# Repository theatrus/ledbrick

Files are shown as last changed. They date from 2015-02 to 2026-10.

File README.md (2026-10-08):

# LEDBrick Project





Open Hardware design for professional aquarium LED lighting systems.

## LEDBrick Plus - Modern ESP32-S3 Based Controller

The **LEDBrick Plus** is a modern, high-performance 8-channel LED driver designed for aquarium lighting applications. Built around the ESP32-S3 microcontroller and ESPHome firmware, it offers professional-grade control with smart home integration.

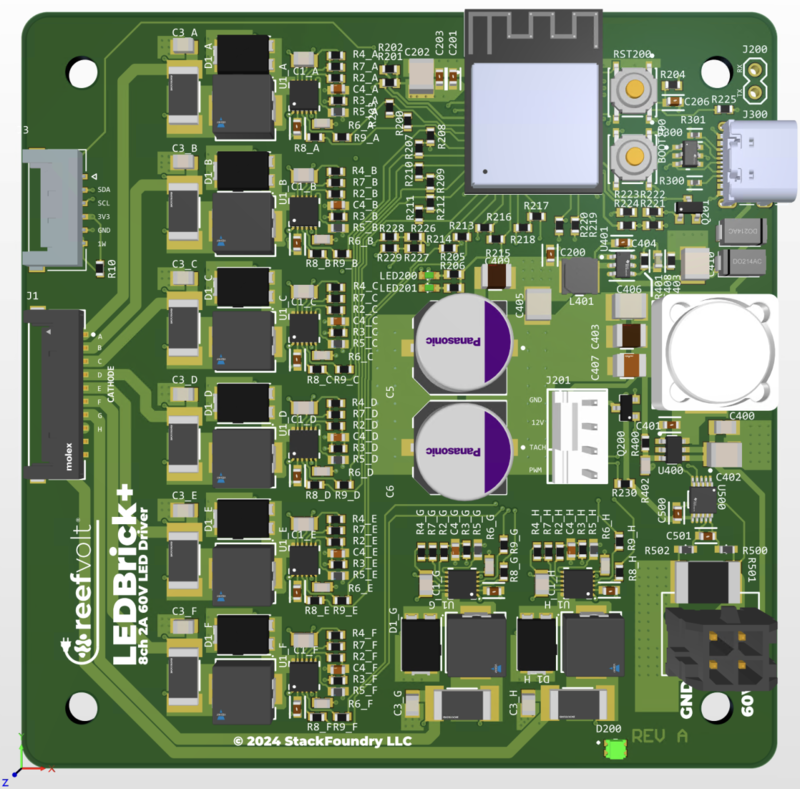
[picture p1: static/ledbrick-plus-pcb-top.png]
LEDBrick Plus PCB - Top View


*Professional 85×85mm PCB with ESP32-S3 microcontroller and 8-channel TPS922053 LED drivers*

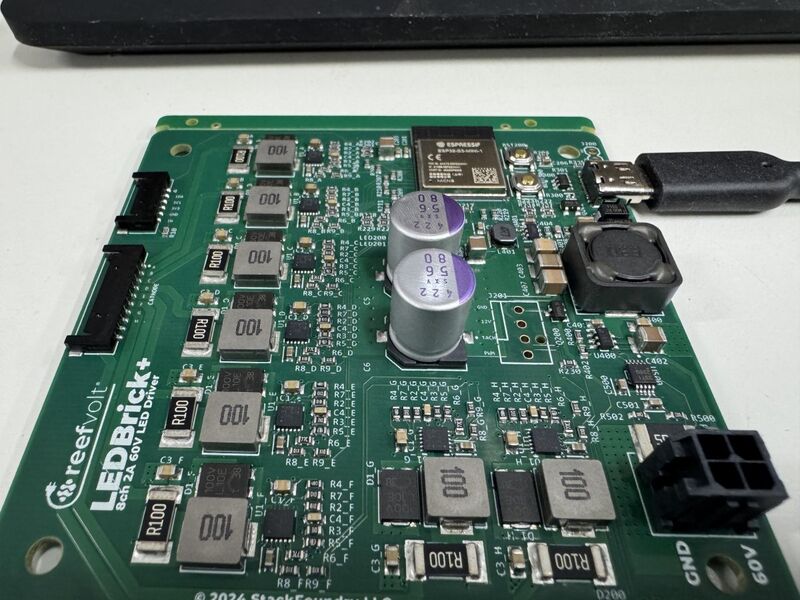
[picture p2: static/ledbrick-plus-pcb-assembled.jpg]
LEDBrick Plus PCB - Assembled


*LEDBrick Plus assembled board showing component placement and professional finish*

### 🚀 Quick Start

**Install firmware directly in your browser:**
👉 **[LEDBrick Plus Web Installer](https://theatrus.github.io/ledbrick/)**

*No downloads or software required - uses WebSerial to flash firmware directly via USB.*

### ⚡ Key Specifications

- **8 Independent LED Channels** with individual PWM and current control
- **High Current Capability**: Up to 2A per channel (scalable design)
- **Wide Voltage Range**: Supports up to 60V input
- **ESP32-S3 Microcontroller**: Dual-core with Wi-Fi connectivity
- **Two dimming controls per channel**: 1 kHz PWM dimming plus a 10 kHz current setpoint (17 PWM outputs including the fan)
- **Precision Current Control**: TPS922053 LED driver chips with 0-2A regulation
- **Environmental Monitoring**: INA228 power monitoring, I2C temperature sensors
- **Fan Control**: 4-wire fan control with RPM monitoring
- **Status Indication**: WS2812 RGB LED with customizable effects
- **Temperature Expansion**: 1-Wire bus for DS18B20 temperature sensors
- **Home Assistant Integration**: Native API with automatic discovery
- **Professional Form Factor**: 85×85mm board designed for marine environments

### 🏠 Smart Home Integration

- **ESPHome Native**: Full Home Assistant integration out of the box
- **Web Interface**: Built-in configuration and monitoring
- **OTA Updates**: Wireless firmware updates
- **MQTT Compatible**: Optional MQTT broker support
- **RESTful API**: HTTP API for custom integrations

### 🌐 Web UI Features

The LEDBrick Plus includes a professional web interface for complete control and monitoring:

#### Schedule Visualization & Control
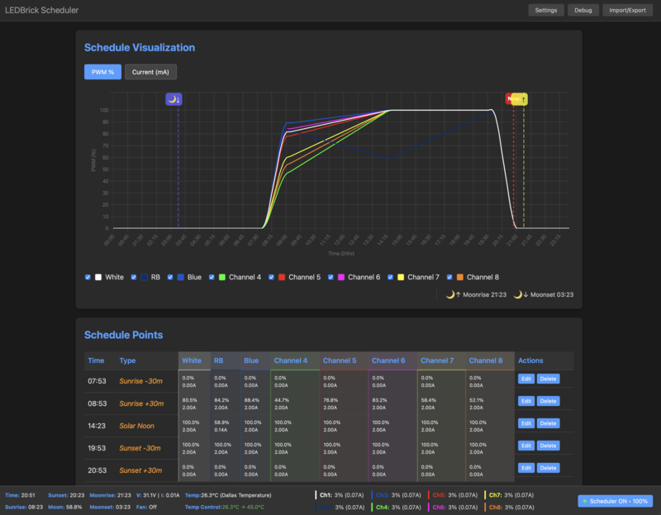
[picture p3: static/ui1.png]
LEDBrick Schedule Visualization


- **Interactive Schedule Graph**: Visual representation of all 8 channels with real-time updates
- **PWM % and Current (mA) Views**: Toggle between percentage and milliamp display modes
- **Moonrise/Moonset Indicators**: Astronomical event markers on the timeline
- **Schedule Point Editor**: Add, edit, and delete schedule points with precise timing
- **Channel Legend**: Color-coded channel identification with individual enable/disable

#### Moon Phase Simulation
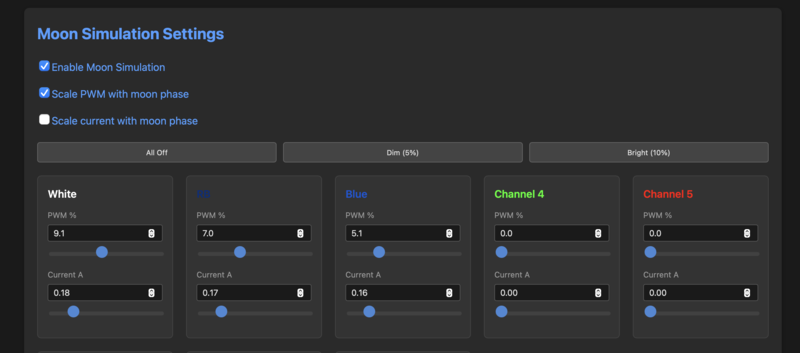
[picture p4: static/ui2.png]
Moon Phase Simulation Settings


- **Moon Phase Integration**: Automatic moon phase calculation based on location
- **PWM & Current Scaling**: Scale channel output based on current moon phase
- **Individual Channel Control**: Manual override sliders for each channel
- **Real-time Current Display**: Live monitoring of actual current draw per channel
- **Quick Presets**: All Off, Dim (5%), and Bright (10%) quick access buttons

#### Schedule Import/Export
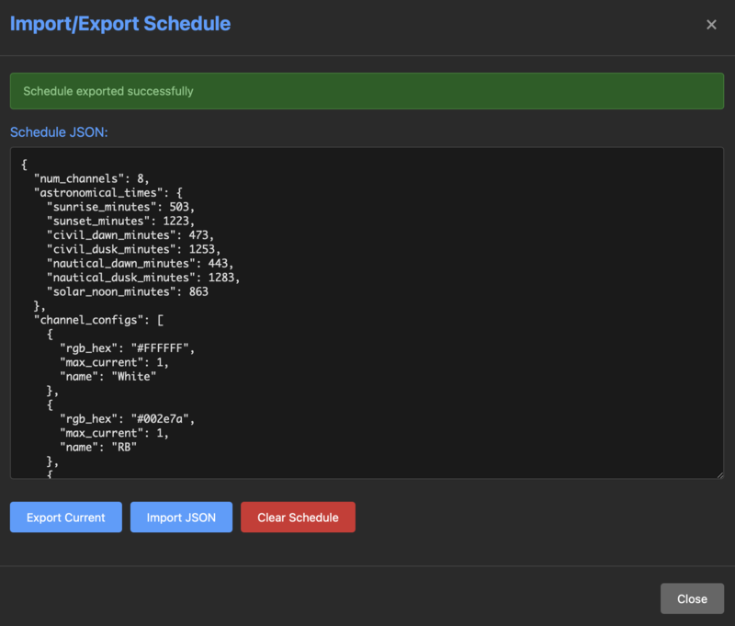
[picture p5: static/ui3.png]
Schedule Import/Export


- **JSON Format**: Human-readable schedule configuration format
- **Backup & Restore**: Export current schedule and import saved configurations
- **Clear Schedule**: Quick reset option for starting fresh
- **Astronomical Timing**: Includes sunrise/sunset offsets and timing parameters

#### Temperature Control System
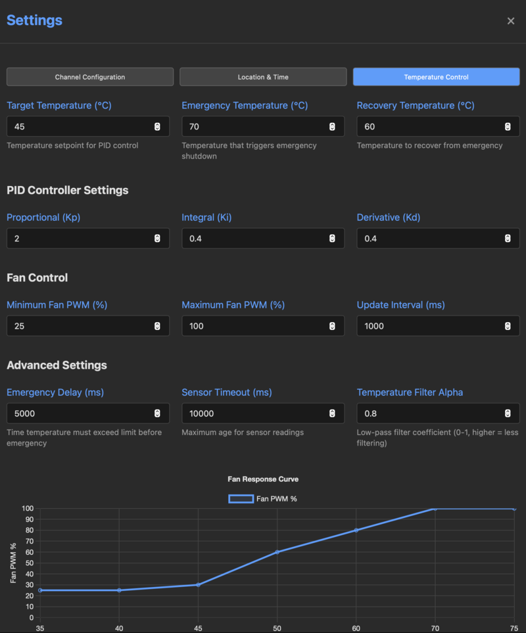
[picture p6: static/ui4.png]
Temperature Control Settings


- **PID Controller Configuration**: Adjustable Kp, Ki, Kd parameters
- **Temperature Thresholds**: Configurable target, emergency, and recovery temperatures
- **Fan Control Settings**: Min/max PWM limits and update intervals
- **Advanced Options**: Emergency delay, sensor timeout, and filter parameters
- **Fan Response Curve**: Visual representation of temperature-to-PWM mapping

#### Channel Configuration
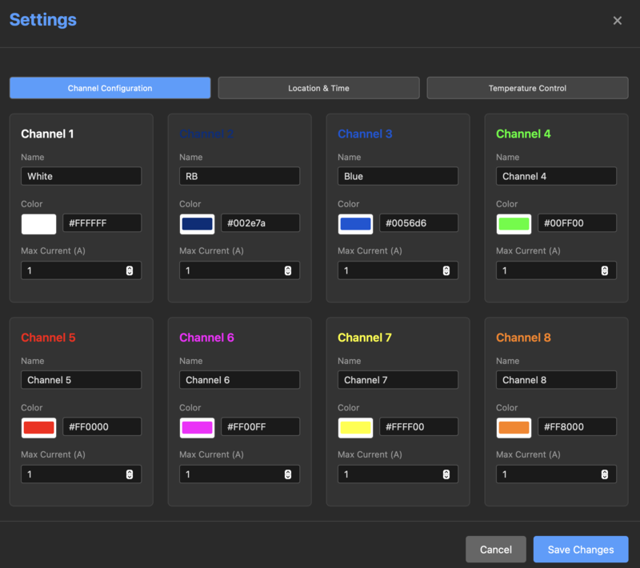
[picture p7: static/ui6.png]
Channel Configuration


- **8 Configurable Channels**: Name, color, and maximum current per channel
- **Visual Color Selection**: Color picker with hex code support
- **Current Limiting**: Hardware-enforced maximum current settings (0-2A)
- **Save/Cancel Options**: Apply changes or revert to previous settings

#### Location & Time Settings
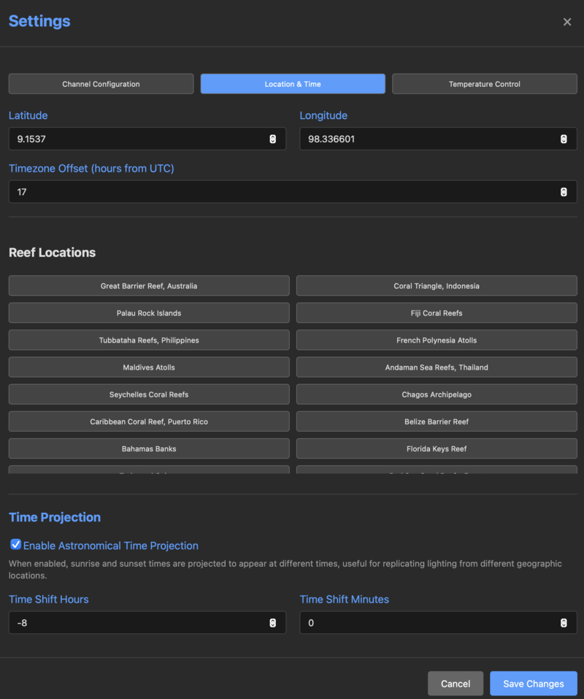
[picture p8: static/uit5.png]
Location and Time Settings


- **Geographic Configuration**: Latitude, longitude, and timezone settings
- **Reef Location Presets**: Quick selection of popular reef locations worldwide
- **Astronomical Time Projection**: Simulate lighting from remote reef locations
- **Time Shift Options**: Hour and minute offsets for schedule adjustment

### 🎛️ Advanced Control Features

- **Individual Channel Control**: Independent PWM brightness and current limiting
- **Smart Current Limiting**: Configurable per-channel maximum current with real-time enforcement
- **Programmable Schedules**: Sunrise/sunset simulation and custom lighting programs
- **Temperature Monitoring**: I2C sensor integration for thermal management
- **Power Monitoring**: Real-time current and voltage monitoring via INA228

### 🔧 Technical Details

**Microcontroller**: ESP32-S3 (Dual-core, 240MHz, Wi-Fi)
**LED Drivers**: 8× TPS922053 constant current drivers
**PWM Frequency**: 1 kHz LED dimming (LEDC), 10 kHz current setpoint (MCPWM), 16 kHz fan (MCPWM)
**Current Range**: 0-2A per channel (1A default limit)
**Input Voltage**: 12-60V DC
**Communication**: Wi-Fi, USB-C, I2C expansion
**Dimensions**: 85×85mm

For detailed forum discussion and community support, see: [Reef2Reef LEDBrick Thread](https://www.reef2reef.com/threads/ledbrick-diy-led-pendant-with-pucks.243746/)

### 📐 Hardware Design Files

Altium Designer sources, release gerbers, pick-and-place, BOM, and DRC reports live under [`hardware/`](hardware/). Two boards make up the LEDBrick Plus system:

- **[`rv_ledbrick_8ch`](hardware/rv_ledbrick_8ch.PrjPcb)** — the **controller / driver board** pictured above. Four-layer FR4 design (top, GND, PWR, bottom — see `G1`/`G2` inner plane gerbers) driven by a hierarchical schematic (`rv_ledbrick_top`, `rv_ledbrick_logic`, `TPS922053_ch`, `usb_input`, `dcdc_60v_12v`, `vin_shunt`) placing 212 components:
  - **Controller**: ESP32-S3-MINI-1-N8 (8 MB flash) with BOOT + RST tactile switches and an Amphenol 10155435 USB-C receptacle for programming and native USB.
  - **Power**: wide-VIN 60V→12V buck front-end (80V 56µF conductive-polymer bulk caps, 68µH main inductor, SS14 Schottky ORing) plus an LMR51610 low-current buck for 3.3V logic.
  - **Power monitoring**: TI INA228 with a 0.005Ω 5W metal-strip shunt on VIN for current/voltage/energy telemetry over I²C.
  - **LED channels (×8)**: TPS922053DRRR 65V/2A synchronous buck LED drivers, each with a 10µH IHLP-style composite inductor, PMEG100V100 100V Schottky flywheel, 0.1Ω 3W current-sense shunt, and an AO3400A n-channel FET + RC network for the dimming/enable input.
  - Release gerbers and pick-and-place in [`Project Outputs for rv_ledbrick_8ch/`](hardware/Project%20Outputs%20for%20rv_ledbrick_8ch/).
- **[`ledbrick_plus_led`](hardware/ledbrick_plus_led.PrjPcb)** — the **LED emitter / pendant board** the controller drives. Single-layer emitter-side copper (typical for a metal-core LED puck), single-sheet schematic, 91 placed parts split across eight channels of high-power emitters:
  - **26× Lumileds LUXEON Rubix Royal Blue** (`L1RX-RYL1000000000`, 1.5A / 1635 lm / 3.16 V each) as the blue/royal backbone.
  - **52× LUXEON C** emitters across many colors: `59`, `39`, PCA, PCB, MNT, VLT (Violet), BLU, RYL, CYN, and DRD bins.
  - **2× VIOSYS Z5** (CUN8) 8-die ultraviolet emitters.
  - 3× onboard temperature sensors: one DS18B20 (1-Wire) plus two MCP9808 (I²C, DFN + MSOP variants) for per-zone thermal feedback.
  - I/O via two Molex Pico-Lock 504050-1091 10-pin connectors and one 6-pin 5040500691 (matches the controller's output headers).
  - Release gerbers in [`ledbrick_plus_led_r0/`](hardware/ledbrick_plus_led_r0/) and [`Project Outputs for ledbrick_plus_led/`](hardware/Project%20Outputs%20for%20ledbrick_plus_led/).

EDM footprint libraries (`*-EDM/`) contain the Parasolid component models referenced by each project. See [`hardware/.gitignore`](hardware/.gitignore) for the list of Altium-generated files that are intentionally excluded.

---

## LEDBrick Classic - Original Design

The original LEDBrick design consists of two main components for DIY aquarium LED lighting.

### Emitter Board

The emitter board is a custom metal-core PCBA designed to hold 8 channels of LEDs from Cree (XP footprint), Osram (SSL and Square), Luxeon (UV and Rebel footprints).

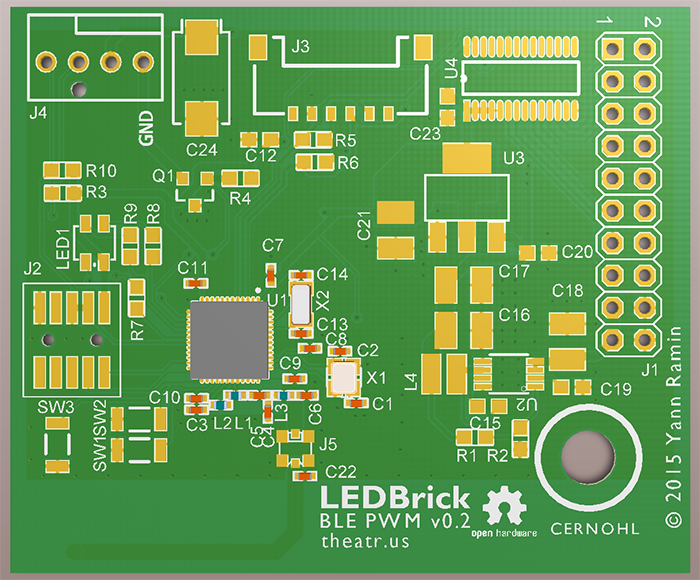
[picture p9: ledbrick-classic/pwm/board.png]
Classic PWM Board


[Design files and gerber files](ledbrick-classic/emitter-board/)

### Bluetooth Low Energy PWM Board (Legacy)

An 8 channel 24VIN + 12VOUT Fan LED dimmer board powered by a Nordic nRF51 Bluetooth Low Energy microcontroller.

[Firmware is available for both Keil and GCC compilers](ledbrick-classic/firmware/nordic_nrf51/app/ble_peripheral/ledbrick_pwm/)
[Design files and gerber files](ledbrick-classic/pwm/0.2/)

For legacy documentation and original design details, see the [ReefCentral thread](http://www.reefcentral.com/forums/showthread.php?t=2477205).

---

## Development

### Building Firmware Locally

```bash
# Install uv (Python package manager)
curl -LsSf https://astral.sh/uv/install.sh | sh

# Clone and build
git clone https://github.com/theatrus/ledbrick.git
cd ledbrick/firmware

# Quick build (runs tests, builds web UI, compiles firmware)
make esphome

# Individual components
make test           # Run all unit tests
make web            # Build React web interface
make web-debug      # Build non-minified web UI (for debugging)
make dev            # Start development server (set LEDBRICK_IP=device-ip)
make preview        # Serve minified build locally (debug minification)
make esphome-debug  # Build firmware with non-minified web UI
make clean-all      # Clean all build artifacts
make help           # Show all available targets
```

### Firmware Features

#### Advanced LED Control
- **8-Channel PWM Control**: Independent brightness and current limiting per channel
- **Smart Current Limiting**: Real-time enforcement of per-channel maximum current settings
- **Astronomical Scheduling**: Sunrise/sunset simulation with location-based timing
- **Time Projection**: Map remote reef locations to local timezone (e.g., Tahiti sunrise at 6AM Pacific)
- **Moon Phase Simulation**: Configurable moon phase effects with intensity scaling
- **Manual Override**: Direct channel control when scheduler is disabled

#### Web Interface
- **React-based UI**: Modern, responsive interface for all device settings
- **Real-time Status**: Live monitoring of channels, sensors, and system status
- **Channel Configuration**: Set names, colors, and maximum current per channel
- **Schedule Management**: Visual schedule editor with interpolation and presets
- **Location Settings**: Built-in reef location presets for accurate astronomical timing
- **Sensor Monitoring**: Display of power consumption, temperature, and fan status
- **Schedule Chart Modes**: Toggle between PWM % and Current (mA) display views
- **Debug Support**: Source maps and non-minified builds for troubleshooting

#### Sensor Integration
- **Power Monitoring**: INA228 current/voltage sensor with real-time display
- **Temperature Sensors**: DS18B20 1-wire sensors for thermal monitoring
- **Fan Control**: PWM speed control with RPM monitoring and on/off state
- **Status Bar**: Responsive layout showing all sensor data and channel status

#### Temperature Control System
- **PID Controller**: Professional-grade temperature regulation with anti-windup protection
- **Multi-Sensor Support**: Average multiple temperature sensors for accurate readings
- **Emergency Thermal Protection**: Automatic shutdown with configurable thresholds
- **Fan Curve Management**: Dynamic fan speed based on temperature with customizable curve
- **Real-time Monitoring**: Temperature status and PID performance metrics in web UI
- **Anti-Oscillation Logic**: Fan maintains minimum speed within 10°C below setpoint

#### Smart Home Integration
- **Home Assistant**: Native ESPHome integration with automatic discovery
- **RESTful API**: Complete HTTP API for schedule management and control
- **OTA Updates**: Wireless firmware updates via ESPHome
- **MQTT Support**: Optional MQTT broker integration

### Development Workflow

#### Testing and Quality Assurance
```bash
# Run unit tests for core algorithms
make test                    # All tests
make test-astro             # Astronomical calculator only
make test-scheduler         # LED scheduler only
make test-clang             # Cross-compiler validation

# Web development
LEDBRICK_IP=192.168.1.xxx make dev    # Development server with device proxy
make web                              # Production build
```

#### Architecture
- **Standalone Components**: Core algorithms (astronomical calculator, LED scheduler) are pure C++ with comprehensive unit tests
- **ESPHome Integration**: Thin wrapper components that integrate with ESPHome ecosystem
- **React Frontend**: TypeScript/React web interface with responsive design
- **Clean Separation**: Core logic can be developed and tested independently of hardware

#### Common Issues and Solutions
- **Compilation Errors**: Run `make clean-all` then `make esphome` for clean rebuild
- **Sensor Configuration**: Ensure sensor IDs match ESPHome configuration exactly
- **Web Interface Debugging**: Use `LEDBRICK_IP=device-ip make dev` for development server
- **API Testing**: Access endpoints directly at `http://device-ip/api/status` etc.

### GitHub Actions

- **Continuous Integration**: Automatic build testing on firmware changes
- **Unit Test Validation**: Standalone component testing with multiple compilers  
- **Web Publishing**: Automated deployment of web installer to GitHub Pages
- **Release Management**: Tagged releases automatically build and publish firmware

## License

Open Source Hardware - see individual component licenses for details.

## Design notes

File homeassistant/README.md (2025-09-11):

# LEDBrick Plus Home Assistant Integration

Simple, focused integration for LEDBrick Plus with Home Assistant. Supports both single unit and multi-unit tank setups.

## Features

- **Direct ESPHome Integration**: Uses native ESPHome entities and services
- **Multi-Unit Support**: Control multiple units as tank groups
- **Clean Dashboards**: Modern UI without complex automations
- **Essential Controls**: Schedule management, brightness, presets
- **Real-time Monitoring**: Power, temperature, and system status

## Quick Start

### 1. Install the Simple Package

Copy `ledbrick_simple_package.yaml` to your Home Assistant packages directory:

```bash
cp ledbrick_simple_package.yaml /config/packages/
```

Enable packages in `configuration.yaml`:
```yaml
homeassistant:
  packages: !include_dir_named packages
```

### 2. Configure Your Units

Edit the `tank_groups` helper in the package:
- **Single unit**: `{"main": ["ledbrickplus"]}`
- **Multiple units**: `{"main": ["ledbrick1", "ledbrick2"], "frag": ["ledbrick3"]}`

### 3. Add a Dashboard

Choose one of the provided dashboards:
- `ledbrick_plus_dashboard.yaml` - Single unit control
- `ledbrick_multi_unit_dashboard.yaml` - Multi-unit with tank groups

## Available Dashboards

### Single Unit Dashboard
Clean interface for controlling one LEDBrick Plus:
- Real-time channel status with colors
- System monitoring (power, temperature, fan)
- Schedule presets and controls
- Temperature control status

### Multi-Unit Dashboard  
Tank-based grouping for multiple units:
- Tank selector with unit overview
- Synchronized controls across units
- Individual unit status cards
- Group actions (brightness, scheduler, presets)

## Key Entities

Each LEDBrick Plus exposes these entities via ESPHome:

### Controls
- `switch.{device}_scheduler_enabled` - Enable/disable scheduler
- `number.{device}_pwm_scale` - Global brightness (0-100%)
- `light.{device}_ch{1-8}_pwm` - Individual channel PWM controls
- `number.{device}_ch{1-8}_current` - Channel current limits
- `number.{device}_ch{1-8}_max_current` - Maximum current settings

### Sensors
- `sensor.{device}_scheduler_pwm_channel_{1-8}` - Current PWM values
- `sensor.{device}_scheduler_current_channel_{1-8}` - Current draw
- `sensor.{device}_ina228_current` - Total current draw
- `sensor.{device}_ina228_bus_voltage` - Input voltage
- `sensor.{device}_dallas_temperature` - Heatsink temperature
- `sensor.{device}_fan_speed` - Fan RPM
- `sensor.{device}_moon_phase` - Current moon phase
- `text_sensor.{device}_ch{1-8}_color` - Channel color configuration

### Services
- `esphome.{device}_load_preset` - Load schedule preset
- `esphome.{device}_clear_schedule` - Clear all schedule points
- `esphome.{device}_set_schedule_point_8ch` - Add schedule point
- `esphome.{device}_get_schedule_json` - Export schedule
- `esphome.{device}_import_schedule_json` - Import schedule

## Simple Package Contents

The `ledbrick_simple_package.yaml` includes:

### Helpers
- `input_text.tank_groups` - JSON tank/unit mapping
- `input_select.active_tank` - Current tank selection
- `input_number.tank_brightness` - Global brightness control
- `input_boolean.sync_units` - Synchronize units toggle
- `input_boolean.feeding_mode` - Simple feeding timer

### Template Sensors
- `sensor.active_tank_units` - Unit count and list
- `sensor.tank_total_power` - Combined power usage
- `sensor.tank_average_temperature` - Average temperature
- `sensor.tank_schedule_status` - Schedule sync status

### Scripts
- `script.ledbrick_load_preset` - Load preset to all units
- `script.ledbrick_clear_schedule` - Clear schedules
- `script.ledbrick_toggle_scheduler` - Toggle schedulers
- `script.ledbrick_set_brightness` - Set brightness
- `script.ledbrick_emergency_off` - Emergency shutdown

### Automations
- Tank brightness synchronization
- Simple 10-minute feeding mode

## Installation Steps

1. **Add ESPHome Device**
   ```yaml
   esphome:
     name: ledbrickplus
     friendly_name: "LEDBrick Plus"
   ```

2. **Install Package**
   - Copy `ledbrick_simple_package.yaml` to `/config/packages/`
   - Restart Home Assistant

3. **Configure Units**
   - Go to Settings → Devices & Services → Helpers
   - Edit "Tank Group Configuration"
   - Add your unit names in JSON format

4. **Add Dashboard**
   - Go to your Lovelace dashboard
   - Add a new card
   - Paste contents from chosen dashboard YAML

## Custom Card Requirements

Install via HACS for full dashboard functionality:
- `custom:button-card` (Required for channel cards)
- `custom:auto-entities` (Required for multi-unit dashboard)
- `custom:multiple-entity-row` (Required for multi-unit dashboard)
- `card-mod` (Optional for styling)

## Tips

- Use the web UI at `http://ledbrickplus.local` for advanced configuration
- Schedule presets: `dynamic_sunrise_sunset`, `full_spectrum`, `simple`
- Moon simulation automatically follows moon phases
- Temperature control maintains safe operating temperatures
- Fan speed adjusts based on temperature

## Troubleshooting

- **Units not syncing**: Check `input_boolean.sync_units` is enabled
- **No data**: Verify ESPHome device names match configuration
- **Missing entities**: Ensure ESPHome firmware is up to date
- **Dashboard errors**: Install required custom cards via HACS

## Support

- [GitHub Issues](https://github.com/theatrus/ledbrick/issues)
- [LEDBrick Forum Thread](https://www.reef2reef.com/threads/ledbrick-diy-led-pendant-with-pucks.243746/)

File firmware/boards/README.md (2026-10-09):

# Boards

What we know about each LEDBrick board, and how to bring more boards up to date.

| Path | What it is |
| --- | --- |
| `ledbrick-plus/channels.json` | The LEDs in each channel, as built. The firmware's default channel LEDs are generated from it. |
| `ledbrick-plus/emitter_netlist.json` | The emitter and controller design files, analysed: strings, driver pins, UV LEDs, sensors, connectors. |
| `ledbrick-plus/FINDINGS.md` | Hardware findings and measurements: driver behaviour, as-built differences, flash storage, test methods. |
| `../tools/led_curves/led_models.json` | Every built-in LED model, standard LED included, with the exact values the firmware uses. Generated. |
| `../tools/led_curves/lumileds_curves.json` | The digitized Lumileds datasheet curves and the standard LED's definition. The models are built from it. |
| `../tools/board_config.py` | Back up, copy and check a board's settings over the web API. |
| `../tools/jtag/` | Read the LED driver registers over USB JTAG, to check what a board outputs. |
| `../tools/ina228_sweep.py` | Measure a channel's current steps and PWM pulse loss with the board's supply current sensor. |
| `ledbrick-plus/measurements/` | The raw data behind the findings. |

## Change the LED data

1. Edit `ledbrick-plus/channels.json` (which LEDs are in a channel) or `tools/led_curves/lumileds_curves.json` (curves).
2. From `firmware/`, run `python3 tools/led_curves/gen_led_models.py`. It rewrites `components/ledbrick_scheduler/led_models.cpp` and `tools/led_curves/led_models.json`. Commit both.
3. Run `make test-led`, then build and flash.

LEDs with no published curve go in as `standard_led`.

## Update a board

1. Back up its settings. From `firmware/`:
   ```bash
   python3 tools/board_config.py backup 192.168.1.196 backups/tank1
   ```
   This saves `schedule.json`, and `led_models.json` with any custom LED models posted to the board. `backups/` is git-ignored: backups hold the tank's schedule and location.
2. Build and flash over the network:
   ```bash
   uvx --from esphome==2026.9.1 esphome run ledbrick-plus.yaml --device 192.168.1.196
   ```
   On Windows, build from PowerShell, not Git Bash: the ESP-IDF install fails under MSYSTEM. `secrets.yaml` in git is a placeholder; use your own.
3. Wait at least a minute before any reset or power cycle. ESPHome marks a new build good after a minute of running. A reset before that rolls the board back to the previous build (boot log: "OTA rollback detected").
4. Check it:
   ```bash
   python3 tools/board_config.py check 192.168.1.196
   ```
   It lists each channel's mode and LEDs, and flags any LED model the board doesn't have.

## Copy settings to another board

```bash
python3 tools/board_config.py apply 192.168.1.197 backups/tank1
```

It posts any custom LED models first, since channels name them, then the schedule. An empty models file is skipped. The PWM scale is not copied. Edit `schedule.json` first if the boards' channels differ.

The built-in models need nothing copied: they are in the firmware. Custom models (`POST /api/led_models`) are only for a part the firmware doesn't know, and they are not normally needed.

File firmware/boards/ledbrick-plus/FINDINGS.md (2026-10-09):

# LEDBrick Plus findings

What we learned bringing up and testing a LEDBrick Plus (8-channel controller `rv_ledbrick_8ch`, emitter `ledbrick_plus_led`, ESP32-S3). Measured on one board in October 2026 unless noted.

## LED driver (TPS922053)

- **Current (ADIM/HD pin):** the driver reads the PWM duty digitally. LED current = 2 A x duty (0.1 ohm sense resistor). It resolves 8 bits up to 39 kHz and 6 bits up to 156 kHz, so one step is 7.8 mA at 8 bits. The first ADIM pulse must be at least 1 us. Minimum on-time is 100-150 ns.
- **Old firmware gave 80 mA steps.** The legacy MCPWM driver ran a 1 MHz timer at about 40 kHz: 25 counts, so only 25 current steps. INA228 supply current showed the staircase and JTAG register reads confirmed the 25-count timer.
- **Fix:** ADIM runs at 10 kHz on `mcpwm_unified`'s new driver (10 MHz timers, 1000 counts, forced levels at 0% and 100%). Pinned in `ledbrick-plus.yaml` (mcpwm_unified PRs #3 and #4, commit 2b5f4cd).
- **Hybrid dimming hazard:** if ADIM stays low while EN/PWM pulses at enable, the driver sets the current from the EN/PWM duty alone, up to 2 A. `packages/channel.yaml` holds EN/PWM off while the commanded current is below 50 mA. EN/PWM low for 57-77 ms disables the driver.
- **EN/PWM (dimming):** 1 kHz, 14-bit (LEDC).
- **The driver rounds the ADIM duty down.** The datasheet doesn't say. Stepping RBCen's command from 98 to 134 mA in 2 mA steps at 100% PWM, supply current rose once per 7.8 mA, and each edge fell where rounding down puts it (between 100 and 102 mA, 108 and 110, and so on); rounding to nearest would put each edge 4 mA lower. The curve dimmer commands mid-step, the most room either side.
- **Checked:** in curve mode at levels 37.5% and 2%, the ADIM compare and LEDC duty read over JTAG matched the dimmer run on a PC, landing on driver steps 50 and 21. LED supply off.

## PWM pulse loss

Each EN/PWM pulse gives less light than its width. Measured on RBCen (13 Rubix, about 38 V) and CW (8 LUXEON C, about 22 V) with the LED supply on, from INA228 supply current against duty at fixed current, with the other channels frozen:

- **Long pulses lose about 19 us each** (1.9% of the 1 kHz period), at 105 mA to 1.2 A on both channels. The best-conditioned fits gave 17-19.5 us; a rougher one (duties 10-60%) gave 30 us. 100% duty has no edges and loses nothing.
- **Short pulses lose less.** The loss sets in over a tail: at 1.2 A it is sharp (1% duty gives about 20% of its light, 3% about 50%); at the floor currents (about 170 mA) it is wide (3% duty gives most of its light). The firmware models light as d - 1.9% x (1 - e^(-d/tail)), with tail 1.9% at 300 mA and above and 4% at 170 mA and below.
- **The driver draws 1-4 mA more supply current** whenever its EN pin is pulsing, without light.
- **Effect on manual mode:** a manual PWM gives (duty - 1.9%) of the light at that current, so 15% PWM gives about 87% of what 15% suggests, and 5% gives about 65%.
- **The curve dimmer allows for it:** it raises each pulsed duty to give the intended light, keeps pulsed duties at or below 97.5% (shorter off-times were not measured), and converts manual settings by the light they really give. Checked on RBCen with the model: 3-25% of a step's light came out within 1% at 1.2 A and within 5% at 168 mA. Without it, 5-10% came out 20-29% dim at 168 mA.
- The INA228 cannot pin the tail below about 3% duty at low currents: the signal there is a few mA against 0.3 mA of noise. A light sensor would.
- To measure another board: `tools/ina228_sweep.py` (current staircase, or PWM sweep with a loss estimate). The data behind these numbers is in `measurements/2026-10-08/`. The sweeps use `/api/channel/control` with the scheduler off and read `/api/status` `total_current`: a new INA228 value every 5 s, averaged over about 0.5 s.

## Emitter, as built

- **WW is not as drawn.** The schematic has 4 LUXEON C 3900K, 2 Deep Red and 2 PC Amber. Built boards have PC Amber in the Deep Red places: 4 3900K and 4 PC Amber. `channels.json` has the as-built list.
- **Violet has 2 UV LEDs:** VIOSYS CUN8 (full part number not in the design files), 4th and 5th in the string. No published curve, so the firmware treats them as standard LEDs.
- **0-ohm jumpers** sit in the PCBlue (mid-string) and violet (cathode end) strings. They are not LEDs.
- **Common anode:** all 8 strings share JA1 pins 1-8; each channel's cathode comes back on JC1.
- **Temperature sensors on the emitter:** two MCP9808 (U1, U3) both at I2C address 0x18, and a DS18B20 on 1-Wire. Both MCP9808s are in the BOM and pick-and-place, so fitting both would clash on the bus. The firmware uses the DS18B20.
- **Harnesses:** the 6-pin sensor connector is mirrored between emitter and controller (pin n to pin 7-n), so that harness reverses pin order. The 10-pin LED harnesses are 1:1.
- Details, with LED designators and positions: `emitter_netlist.json`.

## LED curves

- Curves come from Lumileds DS144 (LUXEON C) and DS309 (LUXEON Rubix), digitized from the PDFs' vector paths: `tools/led_curves/lumileds_curves.json` names the figure and page for each.
- The Rubix uses DS309 2023 thermal data, which matches the emitter BOM. The 2026 revision's current curve is the same.
- Neither datasheet publishes colour or wavelength shift against current, so PWM-first dimming is the choice where colour must not move.
- **Standard LED (`standard_led`):** the point-wise median of nine LUXEON C curves (all but Deep Red), over the range they all cover. Rated 1250 mA, Rth 3.0 C/W. Five of the nine curves stop at 1050 mA; they continue along their last 100 mA to 1250 mA first. Up to 1225 mA the result lies between the real LUXEON C white and mint curves. It stands in for LEDs without a model: the UV LEDs, boards without an LED map, and models lost from flash.
- `tools/led_curves/led_models.json` has every built-in model with the exact values the firmware uses, generated alongside `led_models.cpp`.

## Fan and sensors

- Fan PWM is GPIO37 (16 kHz, inverted), enable GPIO36, tach GPIO35 with an external pull-up. A tach that reads zero while the fan spins was a connector fault, not firmware.
- The 1-Wire bus is noisy: occasional scratchpad CRC errors are normal. The firmware holds a sensor's last good value through 5 failed reads in a row.
- INA228 (I2C 0x40) measures supply voltage and current. With the LED supply on, it shows each current step.

## Settings in flash

- The NVS partition is 448 KB (`partitions.csv`). Settings use two fixed-size records: the schedule (8 KB) and custom LED models (12 KB). Any change rewrites the whole record; an unchanged record is not rewritten.
- A schedule save uses about two 4 KB pages, so each page is erased about once per 50 saves. At 100,000 erase cycles that is about 5 million saves.
- ESPHome holds preference writes for up to a minute. The firmware writes settings 250 ms after the last change, so a power cut soon after a change keeps it.

## Updating and testing

- Wait at least a minute after an OTA update before resetting. A reset before ESPHome marks the build good rolls back to the previous build.
- The USB serial log misses about 2 s after a reset, so setup messages are lost. Check boot results through the API.
- On Windows, build from PowerShell. The ESP-IDF install fails under Git Bash (MSYSTEM).
- JTAG register reads (`tools/jtag/`) show what each pin outputs, independent of the firmware's own reports. Halting the CPU stops the watchdogs, so reset afterwards.

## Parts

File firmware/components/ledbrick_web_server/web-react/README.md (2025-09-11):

# LEDBrick React Web UI

Modern React + TypeScript web interface for the LEDBrick LED controller.

## Features

- **React 18** with TypeScript for type safety
- **Vite** for fast development and optimized builds
- **Chart.js** for schedule visualization
- **Responsive design** for mobile and desktop
- **Real-time updates** via API polling
- **Compressed size**: ~47KB gzipped (includes React framework)

## Development

### Prerequisites

- Node.js 16+ and npm
- LEDBrick device on network or test server

### Quick Start

From the firmware directory:

```bash
# Start development server
make dev

# Enter your device IP when prompted
# Opens browser at http://localhost:3000
```

Or directly in this directory:

```bash
# Install dependencies
npm install

# Start dev server with device proxy
npm run dev:server

# Build production files
npm run build

# Generate C++ web content
npm run generate-cpp
```

### Available Scripts

- `npm run dev` - Start Vite dev server
- `npm run dev:server` - Start dev server with device IP prompt
- `npm run build` - Build production bundles
- `npm run build:analyze` - Build and analyze bundle size
- `npm run generate-cpp` - Generate C++ web_content.cpp
- `npm run size` - Check bundle sizes
- `npm run typecheck` - Run TypeScript type checking

## Architecture

```
web-react/
├── src/
│   ├── api/          # API client
│   ├── components/   # React components
│   ├── hooks/        # Custom React hooks
│   ├── types/        # TypeScript type definitions
│   ├── App.tsx       # Main app component
│   └── main.tsx      # Entry point
├── scripts/
│   ├── generate-web-content.js  # C++ generator
│   └── dev-server.sh           # Dev server with proxy
└── dist/             # Production build output
```

## Build Process

1. **Development**: Vite serves files with hot module replacement
2. **Production Build**: 
   - Vite bundles and minifies all code
   - Outputs: `index.html`, `app.js`, `app.css`
   - Total size: ~47KB gzipped
3. **C++ Generation**:
   - Compresses files with gzip
   - Generates `web_content.cpp` with byte arrays
   - Integrated with ESPHome build

## Size Optimization

The build is optimized for embedded use:

- **Single JS bundle** - No code splitting
- **Aggressive minification** - Terser with multiple passes
- **Gzip compression** - ~70% size reduction
- **Inline critical CSS** - Prevents flash of unstyled content
- **No source maps** - Smaller production build

## API Integration

The app communicates with the LEDBrick device via REST API:

- `/api/schedule` - Get/set schedule
- `/api/status` - Device status and current values
- `/api/presets/*` - Load built-in presets
- `/switch/*` - Control scheduler enable
- `/number/*` - Set PWM scale

## Component Structure

- **App** - Main container, state management
- **Header** - App title
- **ScheduleControls** - Enable/disable, brightness
- **ScheduleTable** - Schedule point editor
- **ScheduleChart** - Visual schedule (TODO)
- **StatusBar** - Current time, sunrise/sunset

## Future Enhancements

- [ ] Complete Chart.js integration
- [ ] Schedule point editor dialog
- [ ] Moon simulation controls
- [ ] Location/astronomical settings
- [ ] Import/export functionality
- [ ] WebSocket for real-time updates

## Troubleshooting

### Build Issues
- Run `npm run clean` to clear caches
- Check Node.js version (16+ required)
- Ensure all dependencies installed

### Dev Server Issues
- Verify device IP is correct
- Check device is on network
- Try direct API access: `http://device-ip/api/status`

### Size Concerns
- Run `npm run build:analyze` to see bundle breakdown
- Consider Preact for 3KB alternative to React
- Enable CDN loading for zero local React size

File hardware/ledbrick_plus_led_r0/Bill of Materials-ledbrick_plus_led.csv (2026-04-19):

Comment | Description | Designator | Footprint | LibRef | Quantity
CAP 0.1uF 50V X7R 0603 | Cap Ceramic 0.1uF 50V X7R 20% SMD 0603 125C Paper T/R | C1, C2, C3 | FP-CL10-IPC_B | CMP-001-00084-7 | 3
5040500691 | CONN WIRE TO BOARD RA 6POS | J1 | MOLEX_5040500691 | CMP-253-000000-2 | 1
504050-1091 | Conn Wire to Board HDR 10 POS 1.5mm Solder RA SMD Pico-Lock™ T/R | JA1, JC1 | FP-504050-1091-MFG | CMP-002-00088-1 | 2
L1RX-RYL1000000000 | LUXEON Rubix High Power LED Royal Blue Square Surface Mount 1635 lm 1.5 A 3.16 V | LED1, LED2, LED3, LED4, LED5, LED6, LED7, LED8, LED9, LED10, LED11, LED12, LED13, LED36, LED37, LED38, LED39, LED40, LED41, LED42, LED43, LED44, LED45, LED46, LED47, LED48 | L1RX-RYL1000000000-Footprint-1 | CMP-007-00052-3 | 26
L1C1-59 |  | LED14, LED15, LED16, LED21, LED22, LED23, LED57, LED58, LED59, LED60, LED61, LED62, LED63, LED64 | LUXEON_C_DATASHEET | CMP-124-0001-3 | 14
L1C1-RYL |  | LED17, LED18, LED19, LED20 | LUXEON_C_DATASHEET | CMP-124-0001-3 | 4
L1C1-PCB |  | LED24, LED25, LED26, LED27, LED30, LED31, LED32, LED33 | LUXEON_C_DATASHEET | CMP-124-0001-3 | 8
L1C1-BLU |  | LED28, LED29, LED34, LED35 | LUXEON_C_DATASHEET | CMP-124-0001-3 | 4
L1C1-VLT |  | LED49, LED50, LED51, LED54, LED55, LED56 | LUXEON_C_DATASHEET | CMP-124-0001-3 | 6
CUN8 |  | LED52, LED53 | VIOSYS_Z5 | CMP-124-0001-3 | 2
L1C1-39 |  | LED65, LED66, LED71, LED72 | LUXEON_C_DATASHEET | CMP-124-0001-3 | 4
L1C1-DRD |  | LED67, LED70 | LUXEON_C_DATASHEET | CMP-124-0001-3 | 2
L1C1-PCA |  | LED68, LED69 | LUXEON_C_DATASHEET | CMP-124-0001-3 | 2
L1C1-MNT |  | LED73, LED75, LED77, LED79 | LUXEON_C_DATASHEET | CMP-124-0001-3 | 4
L1C1-CYN |  | LED74, LED76, LED78, LED80 | LUXEON_C_DATASHEET | CMP-124-0001-3 | 4
0R 1206 | Res Jumper Thick Film 1206 0 Ohm 5% 1/4W Molded SMD Paper T/R | R1, R2 | FP-RC1206-IPC_B | CMP-009-00181-1 | 2
MCP9808T-E/MC | Temp Sensor Digital Serial (2-Wire, I2C) 8-Pin DFN EP T/R | U1 | MCHP-DFN-MC8_V | CMP-010-00024-2 | 1
DS18B20U+T&R | Temp Sensor Digital Serial (1-Wire) 8-Pin uMAX T/R | U2 | MAXM-U8+1_N | CMP-010-00025-1 | 1
MCP9808 | Temp Sensor Digital Serial (2-Wire, I2C) 8-Pin MSOP Tube | U3 | MCHP-MSOP-MS8_M | CMP-114-0012-2 | 1

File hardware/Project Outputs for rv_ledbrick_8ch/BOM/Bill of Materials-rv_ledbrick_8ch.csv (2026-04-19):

Comment | Description | Designator | Footprint | LibRef | Quantity
0R005 HOXLR2817-5W-5MR-1% | Res Metal Strip 2818 0.005 Ohm 1% 5W ±200ppm/°C Pad SMD Automotive T/R | R501 | RESC7146X09N | CMP-009-00241-2 | 1
0.1uF X7R 100V 0805 | Ceramic Capacitor, Multilayer, Ceramic, 100V, 5% +Tol, 5% -Tol, X7R, 15% TC, 0.1uF, Surface Mount, 0805 | C400 | CAPC2013X94X50ML20T25 | CMP-001-00130-1 | 1
4.7k 0603 1% | RES SMD 4.7K OHM 1% 1/10W 0603 | R10 | RESC1608-IPC-LL | CMP-009-00205-1 | 1
7.15k 0603 0.1% | Res Thin Film 0603 7.15K Ohm 0.1% 1/10W ±25ppm/°C Molded SMD SMD Punched Carrier T/R | R402 | RESC1608X55X30NL20T20 | CMP-009-00235-1 | 1
22.1k 0603 0.1% | RES SMD 22.1KOHM 0.1% 1/10W 0603 | R403 | RESC1608-IPC-LL | CMP-009-00207-3 | 1
43045-0428 | PCB Header Temperature range: max. 105 °C Housing Material: Thermoplastic Poles: 4 Rated current: 5 A | J500 | FP-43045-0428-MFG | CMP-002-00096-1 | 1
10155435-00011LF | 16 Position 5 A USB Right Angle Receptacle Connector | J300 | AMPHENOL_10155435-00011LF | CMP-243-000000-3 | 1
5040500691 | CONN WIRE TO BOARD RA 6POS | J3 | MOLEX_5040500691 | CMP-253-000000-2 | 1
C0603C560J5GACTU | Multilayer Ceramic Capacitor, 56 pF, 50 V, ± 5%, C0G (NP0), 0603 [1608 Metric] | C408 | FP-C0603C-CF-IPC_B | CMP-001-00126-1 | 1
CAP 0.47uF 1210 50V X7R | Multilayer Ceramic Capacitor, 0.47 uF, 50 V, ± 10%, X7R, 1210 [3225 Metric] | C406 | CAPC1210(3225)230_M | CMP-001-00128-1 | 1
CAP 10uF 1210 63V X7R | Multilayer Ceramic Capacitors MLCC - SMD/SMT 1210 10uF 63volts *Derate Voltage/Temp | C407 | FP-GRM32E-0_2-0_3-MFG | CMP-001-00119-1 | 1
ESP32-S3-MINI-1-N8 | Bluetooth, WiFi 802.11b/g/n, Bluetooth v5.0 Transceiver Module 2.4GHz PCB Trace Surface Mount | U200 | XCVR_ESP32-S3-MINI-1-N8 | CMP-247-000000-1 | 1
INA228AIDGST | Power Supply Support Circuit, Adjustable, 1 Channel, PDSO10 | U500 | FP-DGS0010A-IPC_C | CMP-015-00018-1 | 1
KK-254-4 | KK 254 Vertical Header, with Friction Lock, 4 Circuits, PC Tail Length: 4.00mm | J201 | KK-254-47053-3000 | CMP-133-0002-3 | 1
LMR51610XFDBVR | SIMPLE SWITCHER® power converter with 4.5V-to-65V 1A synchronous buck and 25µA quiescent current 6-SOT-23 -40 to 150 | U400 | SOT95P280X145-6N | CMP-019-00077-1 | 1
M02PTH |  | J200 | 1X02 | CMP-166-0010-1 | 1
SRN4018-4R7M | Ind Power Semi-Shielded Wirewound 4.7uH 20% 100KHz Ferrite 1.9A 1515 T/R | L401 | FP-SRN4018-MFG | CMP-006-00036-2 | 1
SRR1260-680M | Ind Power Shielded Wirewound 68uH 20% 100KHz 22Q-Factor Ferrite 2.1A T/R | L400 | SRR1260-680M-Footprint-1 | CMP-006-00034-1 | 1
TPS54202DDCR | 4.5V to 28V Input, 2A Output, EMI Friendly Synchronous Step-Down Converter 6-SOT-23-THIN -40 to 125 | U401 | FP-DDC0006A-IPC_C | CMP-019-00081-1 | 1
USBLC6-4SC6 | ESD Suppressor 15KV 6-Pin SOT-23 T/R - Product that comes on tape, but is not reeled | D300 | FP-SOT23-6L-MFG | CMP-004-00040-1 | 1
WS2812B2020 | LED; SMD; 2020; RGB; 2x2x0.84mm; 3.7Ã·5.3V; Lens: transparent; 2kHz | D200 | LED_WS2812B2020 | CMP-004-00042-1 | 1
100k 0603 1% | Res Thick Film 1.6 x 0.8 mm 100K Ohm 1% 0.1W(1/10W) 100ppm/ C Molded SMD Paper T/R | R400, R401 | RESC1608-IPC-LL | CMP-009-00203-1 | 2
100R 0603 1% | Fixed Resistor, Metal Glaze/thick Film, 0.1W, 100ohm, 75V, 1% +/-Tol, 100ppm/Cel, Surface Mount, 0603 | R500, R502 | FP-RC0603-0_55-MFG | CMP-009-00246-1 | 2
504050-1091 | Conn Wire to Board HDR 10 POS 1.5mm Solder RA SMD Pico-Lock™ T/R | J1, J4 | FP-504050-1091-MFG | CMP-002-00088-1 | 2
AC0402FR-075K1L | SMD Chip Resistor, 5.1 kOhm, ± 1%, 63 mW, 0402 [1005 Metric], Thick Film, General Purpose | R300, R301 | FP-AC0402-IPC_A | CMP-009-00234-1 | 2
AO3400A |  | Q200, Q201 | SOT23-3 | CMP-094-0000-1 | 2
CAP 22uF 25V 1210 X7R | 1210 22 uF 25 V ±20% Tolerance X7R Multilayer Ceramic Chip Capacitor | C403, C409 | FP-1210-L_3_2_0_3-W_2_5_0-MFG | CMP-001-00125-1 | 2
CAP 56uF 80V Poly | Conductive Polymer Aluminum Solid Capacitor 56uF 20% 80V Surface Mount T/R | C5, C6 | FP-OS-CON-SMT-F12-MFG | CMP-001-00120-1 | 2
LED0603 |  | LED200, LED201 | LED-0603 | CMP-130-0000-1 | 2
PTS526SK15SMTR2LFS | Switch Tactile N.O. SPST Round Button Gull Wing 0.05A 12VDC 200000Cycles 2.45N SMD T/R | BOOT200, RST200 | FP-PTS526SK15SMTR2LFS-MFG | CMP-011-00015-1 | 2
SS14 |  | D400, D401 | SMA | CMP-080-0002-2 | 2
1K 0603 1% | Res Thick Film 0603 1K Ohm 1% 1/10W ±100ppm/°C Molded SMD Punched Carrier T/R | R205, R206, R230 | RESC1608-IPC-ML | CMP-009-00193-3 | 3
CAP 4.7uF 50V X7R 1210 | CAP CER 4.7UF 50V X7R 1210 | C202, C402, C405, C410 | CAPC3225X20N | CMP-001-00083-3 | 4
CAP 0.1uF 50V X7R 0603 | Cap Ceramic 0.1uF 50V X7R 20% SMD 0603 125C Paper T/R | C200, C201, C401, C404, C500, C501 | FP-CL10-IPC_B | CMP-001-00084-7 | 6
0.001uF 50V 0603 X7R | Ceramic Capacitor, Multilayer, Ceramic, 50V, 10% +Tol, 10% -Tol, X7R, 15% TC, 0.001uF, Surface Mount, 0603 | C4_A, C4_B, C4_C, C4_D, C4_E, C4_F, C4_G, C4_H | FP-0603-L_1_6_0_15-W_0_81-IPC_B | CMP-001-00131-2 | 8
1K 0603 1% | Res Thick Film 0603 1K Ohm 1% 1/10W ±100ppm/°C Molded SMD Punched Carrier T/R | R2_A, R2_B, R2_C, R2_D, R2_E, R2_F, R2_G, R2_H | RESC1608-IPC-NL | CMP-009-00193-3 | 8
1M 0603 1% | VISHAY - CRCW06031M00FKEAHP - RES, AEC-Q200, THICK FILM, 1M, 0603 | R3_A, R3_B, R3_C, R3_D, R3_E, R3_F, R3_G, R3_H | RESC1608-IPC-NL | CMP-009-00187-4 | 8
10K 0603 1% | Res General Purpose Thick Film 0603 10K Ohm 1% 1/10W ±100ppm/°C Molded SMD Paper T/R | R201, R202, R204, R221, R222, R223, R226, R227 | RESC1608-IPC-ML | CMP-009-00191-4 | 8
18k 0603 | Fixed Resistor, Metal Glaze/thick Film, 0.1W, 18000ohm, 75V, 1% +/-Tol, 100ppm/Cel, Surface Mount, 0603 | R5_A, R5_B, R5_C, R5_D, R5_E, R5_F, R5_G, R5_H | FP-CRCW0603-e3-IPC_B | CMP-009-00244-2 | 8
100k 0603 1% | Res Thick Film 1.6 x 0.8 mm 100K Ohm 1% 0.1W(1/10W) 100ppm/ C Molded SMD Paper T/R | R7_A, R7_B, R7_C, R7_D, R7_E, R7_F, R7_G, R7_H | RESC1608-IPC-NL | CMP-009-00203-1 | 8
309k 0603 1% | Res Thick Film 0603 309K Ohm 1% 0.1W(1/10W) ±100ppm/C Molded SMD Paper T/R | R4_A, R4_B, R4_C, R4_D, R4_E, R4_F, R4_G, R4_H | RESC1608-IPC-NL | CMP-009-00208-2 | 8
ERJ-3EKF6192V | Fixed Resistor, Metal Glaze/thick Film, 0.1W, 61900ohm, 75V, 1% +/-Tol, 100ppm/Cel, Surface Mount, 0603 | R6_A, R6_B, R6_C, R6_D, R6_E, R6_F, R6_G, R6_H | RESC1608X55X30ML15T15 | CMP-009-00245-1 | 8
MFL12HR100FT | Fixed Resistor, Metal Strip, 3W, 0.1ohm, 5.48V, 1% +/-Tol, 50ppm/Cel, Surface Mount, 2513 | R1_A, R1_B, R1_C, R1_D, R1_E, R1_F, R1_G, R1_H | FP-CRA2512-MFG | CMP-009-00243-1 | 8
MWSA0603S-100MT | General Purpose Inductor, 10uH, 20%, 1 Element, Composite-Core, SMD, 2525 | L1_A, L1_B, L1_C, L1_D, L1_E, L1_F, L1_G, L1_H | FP-IHLP-2525CZ-FP_2_413x3-MFG | CMP-006-00037-1 | 8
PMEG100V100ELPDZ | Rectifier Diode, Schottky, 1 Phase, 1 Element, 100V V(RRM), Silicon | D1_A, D1_B, D1_C, D1_D, D1_E, D1_F, D1_G, D1_H | DFN355P580X82-3N | CMP-004-00041-2 | 8
TPS922053DRRR | 65-V, 2-A buck LED driver with inductive fast dimming and spread spectrum 12-WSON -40 to 125 | U1_A, U1_B, U1_C, U1_D, U1_E, U1_F, U1_G, U1_H | SON50P300X100_HS-13N | CMP-019-00085-2 | 8
CAP 1uF 10V X7R 0603 | Cap Ceramic 1uF 10V X7R 10% SMD 0603 125C Paper T/R | C2_A, C2_B, C2_C, C2_D, C2_E, C2_F, C2_G, C2_H, C203, C206 | FP-CL10-IPC_B | CMP-001-00085-7 | 10
0.1uF X7R 100V 0805 | Ceramic Capacitor, Multilayer, Ceramic, 100V, 5% +Tol, 5% -Tol, X7R, 15% TC, 0.1uF, Surface Mount, 0805 | C1_A, C1_B, C1_C, C1_D, C1_E, C1_F, C1_G, C1_H, C3_A, C3_B, C3_C, C3_D, C3_E, C3_F, C3_G, C3_H | CAPC2013X94X50NL20T25 | CMP-001-00130-1 | 16
10K 0603 1% | Res General Purpose Thick Film 0603 10K Ohm 1% 1/10W ±100ppm/°C Molded SMD Paper T/R | R200, R203, R207, R208, R209, R210, R211, R212, R213, R214, R215, R216, R217, R218, R219, R220, R225 | RESC1608-IPC-NL | CMP-009-00191-4 | 17
10R 0603 1% | YAGEO (PHYCOMP) - RC0603FR-0710RL - RES, THICK FILM, 10R, 1%, 0.1W, 0603 | R8_A, R8_B, R8_C, R8_D, R8_E, R8_F, R8_G, R8_H, R9_A, R9_B, R9_C, R9_D, R9_E, R9_F, R9_G, R9_H, R224, R228, R229 | RESC1608-IPC-NL | CMP-009-00180-2 | 19

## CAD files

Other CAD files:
hardware/ledbrick_plus_led-EDM/FP-504050-1091-MFG_CMP-002-00088-1.x_t
hardware/ledbrick_plus_led-EDM/FP-CL10-IPC_B_CMP-001-00084-7.x_t
hardware/ledbrick_plus_led-EDM/FP-RC1206-IPC_B_CMP-009-00181-1.x_t
hardware/ledbrick_plus_led-EDM/L1RX-RYL1000000000-Footprint-1_CMP-007-00052-3.x_t
hardware/ledbrick_plus_led-EDM/LUXEON_C_DATASHEET_CMP-124-0001-3.x_t
hardware/ledbrick_plus_led-EDM/LUXEON_C_WIDE_CMP-124-0001-2.x_t
hardware/ledbrick_plus_led-EDM/MAXM-U8+1_N_CMP-010-00025-1.x_t
hardware/ledbrick_plus_led-EDM/MCHP-DFN-MC8_V_CMP-010-00024-2.x_t
hardware/ledbrick_plus_led-EDM/MCHP-MSOP-MS8_M_CMP-114-0012-2.x_t
hardware/ledbrick_plus_led-EDM/MOLEX_5040500691_CMP-253-000000-2.x_t
hardware/ledbrick_plus_led-EDM/VIOSYS_Z5_CMP-124-0001-3.x_t
hardware/rv_ledbrick_8ch-EDM/AMPHENOL_10155435-00011LF_CMP-243-000000-3.x_t
hardware/rv_ledbrick_8ch-EDM/CAPC1210(3225)230_M_CMP-001-00128-1.x_t
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

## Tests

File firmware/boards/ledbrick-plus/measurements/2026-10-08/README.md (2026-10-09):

# Driver measurements, 2026-10-08

One LEDBrick Plus, LED supply on (50.9 V), other channels frozen at their schedule values. Each file lists the commands sent (`pwm` in %, `current` in A) and the INA228 supply current readings (A) after each, plus readings with the channel off (`baselines`). Channels are 1-based. Findings: `../../FINDINGS.md`.

| File | Channel | What |
| --- | --- | --- |
| `staircase_ch5.json` | 5 RBCen | 100% PWM, current 98-134 mA in 2 mA steps: driver steps and rounding |
| `pwm_sweep_ch5.json` | 5 | Duty 1-25% at 1.2 A and 164 mA |
| `pwm_sweep2_ch5.json` | 5 | Duty 2-100% at 164 and 300 mA |
| `pwm_sweep_ch2.json` | 2 CW | Duty 2-100% at 105 and 200 mA, 2-15% at 1.0 A |
| `pwm_high_ch2.json` | 2 | Duty 40-100% at 105 and 200 mA: pulse loss near full duty |
| `pwm_high_ch5.json` | 5 | Duty 40-100% at 164 mA |
| `floor_check_ch5.json` | 5 | 168 mA: shares 2-25% sent as plain duty (`old`) and with the first loss model (`new`) |
| `floor_check2_ch5.json` | 5 | 168 mA: shares 2-25% with the final loss model |
| `pwmfirst_check_ch5.json` | 5 | 1.2 A: shares 2-25% with the final loss model |
| `tool_pwm_ch5.json`, `tool_stair_ch5.json` | 5 | Trial runs of `tools/ina228_sweep.py` |

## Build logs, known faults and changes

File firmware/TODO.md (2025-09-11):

# LEDBrick Scheduler - Home Assistant Services Implementation

## Overview
The LEDBrick Scheduler C++ component includes a planned Home Assistant services architecture that was partially implemented but needs completion due to ESPHome API service registration complexity.

## Planned Services Architecture

### 1. Schedule Management Services

#### `ledbrick_scheduler.set_schedule_point`
**Purpose:** Add or update a schedule point for all channels
**Parameters:**
- `time_minutes` (int, 0-1439): Time in minutes from midnight (e.g., 480 = 8:00 AM)
- `pwm_values` (float array): PWM percentages (0-100) for each channel
- `current_values` (float array): Current values (0-2A) for each channel

**Example Usage:**
```yaml
# Home Assistant automation
service: ledbrick_scheduler.set_schedule_point
data:
  time_minutes: 480  # 8:00 AM
  pwm_values: [0, 20, 60, 80, 60, 40, 20, 0]  # 8 channels
  current_values: [0, 0.3, 1.0, 1.5, 1.0, 0.6, 0.3, 0]
```

#### `ledbrick_scheduler.remove_schedule_point`
**Purpose:** Remove a schedule point at specific time
**Parameters:**
- `time_minutes` (int): Time point to remove

#### `ledbrick_scheduler.clear_schedule`
**Purpose:** Remove all schedule points
**Parameters:** None

### 2. Preset Management Services

#### `ledbrick_scheduler.load_preset`
**Purpose:** Load a built-in or saved preset schedule
**Parameters:**
- `preset_name` (string): Name of preset to load

**Built-in Presets:**
- `sunrise_sunset`: Natural lighting cycle (4 points: dawn, noon, dusk, night)
- `full_spectrum`: High-intensity full spectrum (4 points: morning, midday, afternoon, evening)
- `simple`: Basic on/off schedule (2 points: 8AM on, 8PM off)

**Example Usage:**
```yaml
service: ledbrick_scheduler.load_preset
data:
  preset_name: "sunrise_sunset"
```

#### `ledbrick_scheduler.save_preset`
**Purpose:** Save current schedule as named preset
**Parameters:**
- `preset_name` (string): Name for the new preset

### 3. Control Services

#### `ledbrick_scheduler.set_enabled`
**Purpose:** Enable or disable the scheduler
**Parameters:**
- `enabled` (boolean): True to enable, false to disable

#### `ledbrick_scheduler.get_status`
**Purpose:** Get current scheduler status and interpolated values
**Parameters:** None
**Returns:** Fires Home Assistant event with current status

### 4. Advanced Services (Future)

#### `ledbrick_scheduler.set_interpolation_curve`
**Purpose:** Change interpolation method between schedule points
**Parameters:**
- `curve_type` (string): "linear", "smooth", "bezier"

#### `ledbrick_scheduler.sync_sunrise_sunset`
**Purpose:** Automatically sync schedule points to sunrise/sunset times
**Parameters:**
- `location` (object): Latitude/longitude for sun calculations

## Current Implementation Status

### ✅ Completed (Updated Implementation)
- **C++ Component**: Professional LEDBrickScheduler class with complete scheduling logic
- **Python Integration**: ESPHome codegen integration and automation actions
- **Template-Based Services**: Native ESPHome service system with individual channel parameters
- **Local Storage**: Binary format persistence to ESP32 flash memory (4KB storage)
- **Home Assistant Integration**: Complete UI helpers, scripts, and automations
- **Preset System**: Built-in presets (sunrise_sunset, full_spectrum, simple)
- **Linear Interpolation**: Smooth transitions between schedule points
- **Current Limiting**: Per-channel maximum current enforcement
- **Status Reporting**: Template sensors for monitoring scheduler state

### ✅ Working Services (Template-Based Approach)
- `set_schedule_point_8ch` - Set schedule point for all 8 channels
- `set_schedule_point_4ch` - Simplified 4-channel version for testing  
- `remove_schedule_point` - Remove schedule point at specific time
- `clear_schedule` - Remove all schedule points
- `load_preset` - Load built-in or saved presets
- `save_preset` - Save current schedule as named preset
- `set_scheduler_enabled` - Enable/disable scheduler
- `get_scheduler_status` - Log current status and values
- `export_schedule` - Export schedule as JSON to logs
- `save_to_flash` / `load_from_flash` - Manual flash storage operations

### ❌ Previous Approach (Documented as Not Working)
- ESPHome CustomAPIDevice service registration with `std::vector<float>` parameters
- Direct C++ service method binding (linking errors)
- Complex parameter type serialization (template specialization issues)

## Implementation Approaches

### ✅ Option 2: ESPHome Native Services (IMPLEMENTED)
**Status:** Successfully implemented and tested
**Approach:** Define services in YAML and connect to component methods via lambda functions
**Benefits:**
- No linking issues with complex parameter types
- Works with existing ESPHome infrastructure
- Full control over parameter validation and conversion
- Easy to extend and modify

**Example Implementation:**
```yaml
api:
  services:
    - service: set_schedule_point_8ch
      variables:
        time_minutes: int
        pwm_ch1: float
        pwm_ch2: float
        # ... all 8 channels for both PWM and current
      then:
        - lambda: |-
            std::vector<float> pwm_values = {pwm_ch1, pwm_ch2, pwm_ch3, pwm_ch4, pwm_ch5, pwm_ch6, pwm_ch7, pwm_ch8};
            std::vector<float> current_values = {current_ch1, current_ch2, current_ch3, current_ch4, current_ch5, current_ch6, current_ch7, current_ch8};
            id(main_scheduler).set_schedule_point(time_minutes, pwm_values, current_values);
```

### ❌ Option 1: ESPHome CustomAPIDevice Services (FAILED)
**Status:** Attempted but blocked by linking errors
**Issue:** ESPHome's CustomAPIDevice has incomplete template specializations for `std::vector<float>` parameters
**Conclusion:** Not viable with current ESPHome version

### ✅ Option 3: Home Assistant Template Integration (IMPLEMENTED)
**Status:** Complete with UI helpers, scripts, and automations
**Approach:** Home Assistant provides rich UI and logic, calls ESPHome services with individual parameters
**Benefits:**
- Rich Home Assistant dashboard integration
- Input helpers for easy configuration
- Automated scheduling via time-based automations
- Script shortcuts for common configurations

## Implementation Complete

### ✅ Ready for Use
The LEDBrick Scheduler is now fully implemented with:

1. **ESPHome Component**: Professional C++ scheduler with flash storage (`components/ledbrick_scheduler/`)
2. **Service Integration**: Template-based services for Home Assistant (`packages/scheduler_services.yaml`)  
3. **Home Assistant Helpers**: Complete UI and automation configuration (`homeassistant_integration.yaml`)
4. **Test Configuration**: Working example with all 8 channels (`test_scheduler_with_services.yaml`)

### Quick Start
1. **Enable in LEDBrick**: Uncomment scheduler package line in `ledbrick-plus.yaml:78`
2. **Add External Component**: Include scheduler component in configuration
3. **Import HA Config**: Copy `homeassistant_integration.yaml` to Home Assistant
4. **Configure Schedule**: Use Home Assistant UI or call services directly

### Usage Examples
```bash
# Load a preset via ESPHome service
service: esphome.ledbrickplus_load_preset
data:
  preset_name: "sunrise_sunset"

# Set custom schedule point  
service: esphome.ledbrickplus_set_schedule_point_8ch
data:
  time_minutes: 480  # 8:00 AM
  pwm_ch1: 0
  pwm_ch2: 20
  # ... etc for all channels
```

## Service Interface Design Goals

- **Simple:** Easy to call from Home Assistant automations
- **Flexible:** Support both individual channel control and preset loading  
- **Efficient:** Minimal Home Assistant entity overhead
- **Extensible:** Easy to add advanced features like curve interpolation
- **Robust:** Proper error handling and validation

## Example Home Assistant Integration

```yaml
# automation.yaml
automation:
  - alias: "Morning Lighting Schedule"
    trigger:
      - platform: time
        at: "06:00:00"
    action:
      - service: ledbrick_scheduler.load_preset
        data:
          preset_name: "sunrise_sunset"
      - service: ledbrick_scheduler.set_enabled
        data:
          enabled: true

  - alias: "Custom Evening Lighting"  
    trigger:
      - platform: time
        at: "20:00:00"
    action:
      - service: ledbrick_scheduler.set_schedule_point
        data:
          time_minutes: 1200  # 8 PM
          pwm_values: [10, 20, 30, 40, 30, 20, 10, 5]
          current_values: [0.2, 0.4, 0.6, 0.8, 0.6, 0.4, 0.2, 0.1]
```

This architecture provides a clean, professional interface for managing complex lighting schedules while maintaining the performance benefits of the C++ implementation.

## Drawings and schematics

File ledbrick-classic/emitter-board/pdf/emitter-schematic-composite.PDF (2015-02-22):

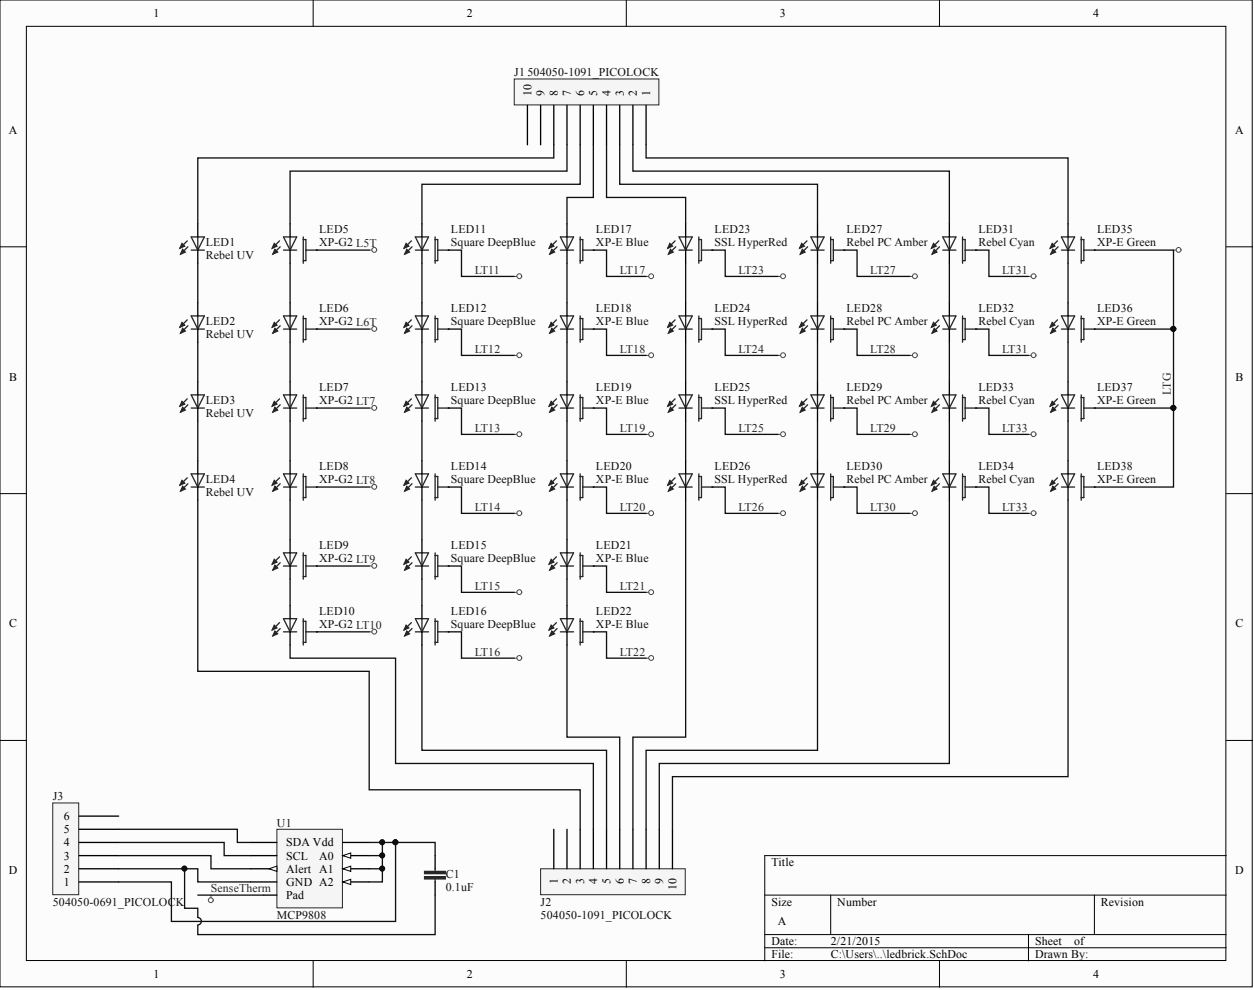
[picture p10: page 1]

SCL A0 Alert A1 GND A2 Pad

SenseTherm

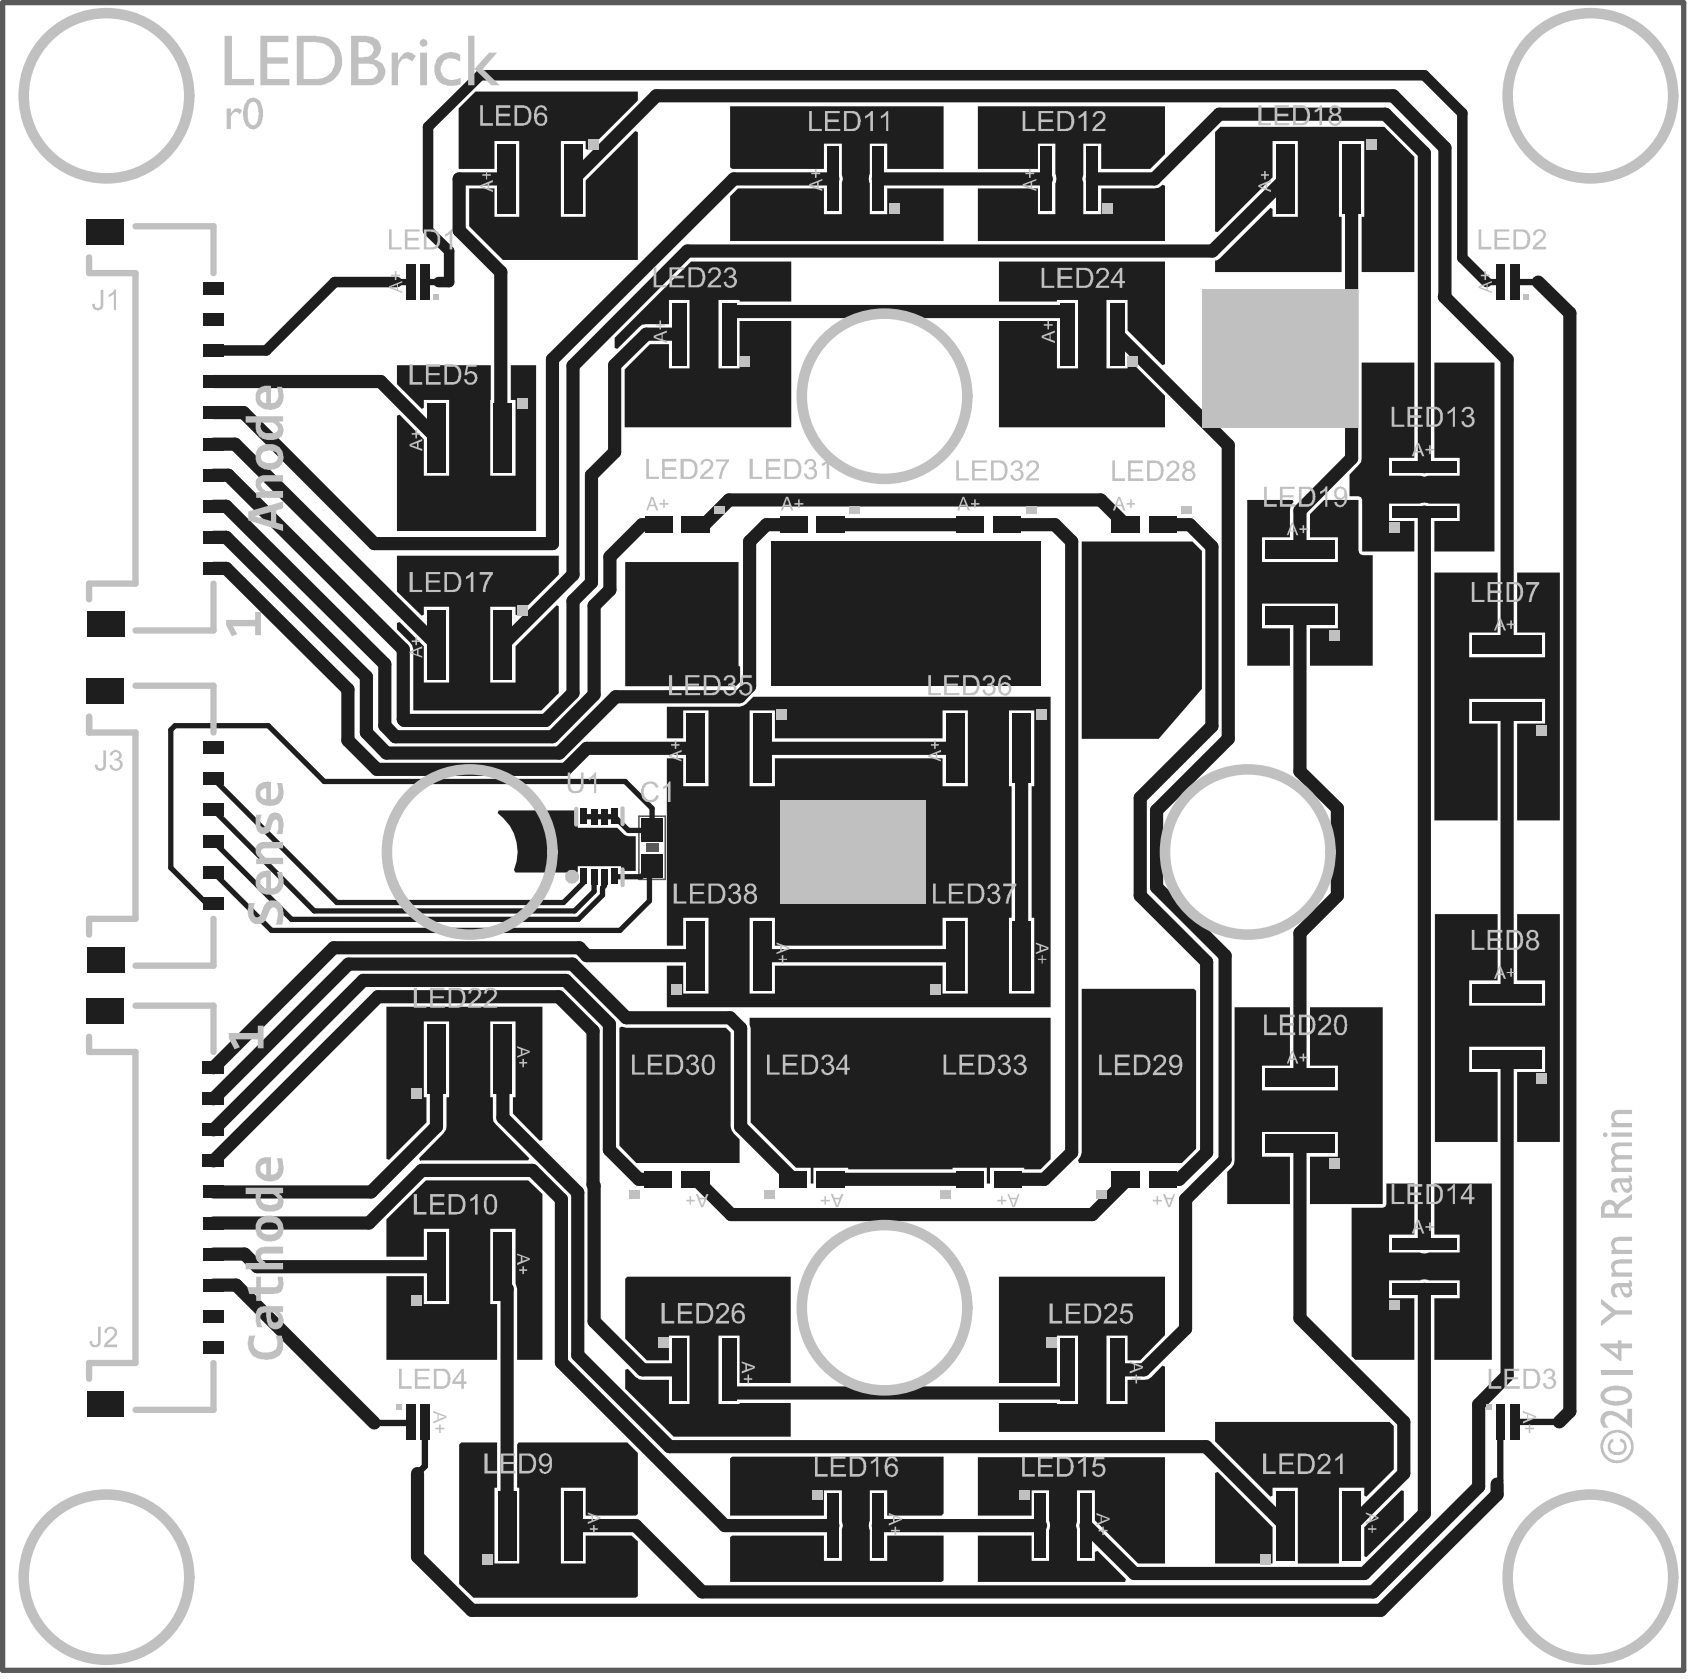
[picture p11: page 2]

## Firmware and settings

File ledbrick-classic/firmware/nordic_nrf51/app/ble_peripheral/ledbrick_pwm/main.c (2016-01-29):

/* Copyright (c) 2014 Nordic Semiconductor. All Rights Reserved.
 *
 * The information contained herein is property of Nordic Semiconductor ASA.
 * Terms and conditions of usage are described in detail in NORDIC
 * SEMICONDUCTOR STANDARD SOFTWARE LICENSE AGREEMENT.
 *
 * Licensees are granted free, non-transferable use of the information. NO
 * WARRANTY of ANY KIND is provided. This heading must NOT be removed from
 * the file.
 *
 */

/** @file
 *
 * @defgroup ble_sdk_app_template_main main.c
 * @{
 * @ingroup ble_sdk_app_template
 * @brief Template project main file.
 *
 * This file contains a template for creating a new application. It has the code necessary to wakeup
 * from button, advertise, get a connection restart advertising on disconnect and if no new
 * connection created go back to system-off mode.
 * It can easily be used as a starting point for creating a new application, the comments identified
 * with 'YOUR_JOB' indicates where and how you can customize.
 */

#include <stdint.h>
#include <string.h>
#include <inttypes.h>
#include "nordic_common.h"
#include "nrf.h"
#include "app_error.h"
#include "nrf51_bitfields.h"
#include "ble.h"
#include "ble_hci.h"
#include "ble_srv_common.h"
#include "ble_advdata.h"
#include "ble_advertising.h"
#include "ble_conn_params.h"
#include "boards.h"
#include "softdevice_handler.h"
#include "app_timer.h"
#include "device_manager.h"
#include "pstorage.h"
#include "app_trace.h"
#include "bsp.h"
#include "bsp_btn_ble.h"
#include "ble_lbs.h"
#include "twi_master.h"
#include "pca9685.h"
#include "mcp9808.h"
#include "fan_monitor.h"
#include "error_handlers.h"

#define IS_SRVC_CHANGED_CHARACT_PRESENT  1                                          /**< Include or not the service_changed characteristic. if not enabled, the server's database cannot be changed for the lifetime of the device*/

#define DEVICE_NAME                      "LEDBrick-PWM"                               /**< Name of device. Will be included in the advertising data. */
#define MANUFACTURER_NAME                "theatr.us"                      /**< Manufacturer. Will be passed to Device Information Service. */
#define APP_ADV_INTERVAL                 300                                        /**< The advertising interval (in units of 0.625 ms. This value corresponds to 25 ms). */
#define APP_ADV_TIMEOUT_IN_SECONDS       86400                                        /**< The advertising timeout in units of seconds. */

#define APP_TIMER_PRESCALER              0                                          /**< Value of the RTC1 PRESCALER register. */
#define APP_TIMER_MAX_TIMERS             (7+BSP_APP_TIMERS_NUMBER)                  /**< Maximum number of simultaneously created timers. */
#define APP_TIMER_OP_QUEUE_SIZE          8                                          /**< Size of timer operation queues. */

#define MIN_CONN_INTERVAL                MSEC_TO_UNITS(50, UNIT_1_25_MS)           /**< Minimum acceptable connection interval (0.05 seconds). */
#define MAX_CONN_INTERVAL                MSEC_TO_UNITS(200, UNIT_1_25_MS)           /**< Maximum acceptable connection interval (.2 second). */
#define SLAVE_LATENCY                    0                                          /**< Slave latency. */
#define CONN_SUP_TIMEOUT                 MSEC_TO_UNITS(4000, UNIT_10_MS)            /**< Connection supervisory timeout (4 seconds). */

#define FIRST_CONN_PARAMS_UPDATE_DELAY   APP_TIMER_TICKS(5000, APP_TIMER_PRESCALER) /**< Time from initiating event (connect or start of notification) to first time sd_ble_gap_conn_param_update is called (5 seconds). */
#define NEXT_CONN_PARAMS_UPDATE_DELAY    APP_TIMER_TICKS(30000, APP_TIMER_PRESCALER)/**< Time between each call to sd_ble_gap_conn_param_update after the first call (30 seconds). */
#define MAX_CONN_PARAMS_UPDATE_COUNT     3                                          /**< Number of attempts before giving up the connection parameter negotiation. */

#define SEC_PARAM_BOND                   1                                          /**< Perform bonding. */
#define SEC_PARAM_MITM                   0                                          /**< Man In The Middle protection not required. */
#define SEC_PARAM_IO_CAPABILITIES        BLE_GAP_IO_CAPS_NONE                       /**< No I/O capabilities. */
#define SEC_PARAM_OOB                    0                                          /**< Out Of Band data not available. */
#define SEC_PARAM_MIN_KEY_SIZE           7                                          /**< Minimum encryption key size. */
#define SEC_PARAM_MAX_KEY_SIZE           16                                         /**< Maximum encryption key size. */

#define DEAD_BEEF                        0xDEADBEEF                                 /**< Value used as error code on stack dump, can be used to identify stack location on stack unwind. */

static dm_application_instance_t         m_app_handle;                               /**< Application identifier allocated by device manager */
static ble_lbs_t                         m_lbs;
static uint16_t                          m_conn_handle = BLE_CONN_HANDLE_INVALID;   /**< Handle of the current connection. */
static app_timer_id_t                    m_apptimer_id;

#define LEDBUTTON_LED_PIN_NO            BSP_LED_1
#define LEDBUTTON_BUTTON_PIN_NO         BSP_BUTTON_1

#define TWI0_CONFIG_FREQUENCY NRF_TWI_FREQ_100K
#define TWI0_CONFIG_IRQ_PRIORITY 0


void assert_nrf_callback(uint16_t line_num, const uint8_t * p_file_name)
{
    app_error_handler(DEAD_BEEF, line_num, p_file_name);
}


static void timers_init(void)
{
    // Initialize timer module.
    APP_TIMER_INIT(APP_TIMER_PRESCALER, APP_TIMER_MAX_TIMERS, APP_TIMER_OP_QUEUE_SIZE, false);
}


/**@brief Function for the GAP initialization.
 *
 * @details This function sets up all the necessary GAP (Generic Access Profile) parameters of the
 *          device including the device name, appearance, and the preferred connection parameters.
 */
static void gap_params_init(void)
{
    uint32_t                err_code;
    ble_gap_conn_params_t   gap_conn_params;
    ble_gap_conn_sec_mode_t sec_mode;

    BLE_GAP_CONN_SEC_MODE_SET_OPEN(&sec_mode);

    err_code = sd_ble_gap_device_name_set(&sec_mode,
                                          (const uint8_t *)DEVICE_NAME,
                                          strlen(DEVICE_NAME));
    APP_ERROR_CHECK(err_code);

    /* YOUR_JOB: Use an appearance value matching the application's use case.
       err_code = sd_ble_gap_appearance_set(BLE_APPEARANCE_);
       APP_ERROR_CHECK(err_code); */

    memset(&gap_conn_params, 0, sizeof(gap_conn_params));

    gap_conn_params.min_conn_interval = MIN_CONN_INTERVAL;
    gap_conn_params.max_conn_interval = MAX_CONN_INTERVAL;
    gap_conn_params.slave_latency     = SLAVE_LATENCY;
    gap_conn_params.conn_sup_timeout  = CONN_SUP_TIMEOUT;

    err_code = sd_ble_gap_ppcp_set(&gap_conn_params);
    APP_ERROR_CHECK(err_code);
}

static void on_conn_params_evt(ble_conn_params_evt_t * p_evt)
{
//    uint32_t err_code;

    if (p_evt->evt_type == BLE_CONN_PARAMS_EVT_FAILED)
    {
        //err_code = sd_ble_gap_disconnect(m_conn_handle, BLE_HCI_CONN_INTERVAL_UNACCEPTABLE);
        //APP_ERROR_CHECK(err_code);
    }
}

static void conn_params_error_handler(uint32_t nrf_error)
{
    APP_ERROR_HANDLER(nrf_error);
}


/**@brief Function for initializing the Connection Parameters module.
 */
static void conn_params_init(void)
{
    //uint32_t               err_code;
    ble_conn_params_init_t cp_init;

    memset(&cp_init, 0, sizeof(cp_init));

    cp_init.p_conn_params                  = NULL;
    cp_init.first_conn_params_update_delay = FIRST_CONN_PARAMS_UPDATE_DELAY;
    cp_init.next_conn_params_update_delay  = NEXT_CONN_PARAMS_UPDATE_DELAY;
    cp_init.max_conn_params_update_count   = MAX_CONN_PARAMS_UPDATE_COUNT;
    cp_init.start_on_notify_cccd_handle    = BLE_GATT_HANDLE_INVALID;
    cp_init.disconnect_on_fail             = false;
    cp_init.evt_handler                    = on_conn_params_evt;
    cp_init.error_handler                  = conn_params_error_handler;

	  // Disabled as this currently makes the Paypal GATT server
	  // unhappy - it disconnects even though told not to.
	
    //err_code = ble_conn_params_init(&cp_init);
    //APP_ERROR_CHECK(err_code);
}

static void led_write_all(uint8_t power) {
    for (int i = 0; i < 16; i++) {
        pca9685_write_led(i, 0x0, power << 4);
    }
}

static void led_write_handler(ble_lbs_t * p_lbs, uint8_t led, uint8_t power) {
    nrf_gpio_pin_toggle(LEDBUTTON_LED_PIN_NO);
    if (error_any()) {
        led_write_all(0);
        return;
    }

    if (led == 0xFF) { // All LEDs
        led_write_all(power);
    } else if (led == 0xFE) {
        pca9685_enable(power);
    } else {
        pca9685_write_led(led, 0x0, power << 4);
    }
}

static void polled_event_update(void* p) {
    uint16_t rpm = fantach_rpm();
    uint8_t rpma[2] = { rpm & 0xFF, rpm >> 8 };
    ble_lbs_update_fan(&m_lbs, rpma);
		uint16_t temp = mcp9808_temp();
		uint8_t tempa[2] = { temp & 0XFF, temp >> 8};
		ble_lbs_update_temp(&m_lbs, tempa);

		// Do fan movement logic
		if (temp > 0 && temp < 30) {
			fantach_disable();
		} else if (temp == 0 || temp > 42) {
			fantach_enable();
		}
		
		if (temp > 65) {
			error_raise(ERROR_TEMP);
		}
		
    if (error_any()) {
        led_write_all(0);
    }
}


static void application_timers_start(void) {
    app_timer_create(&m_apptimer_id, APP_TIMER_MODE_REPEATED, polled_event_update);
    app_timer_start(m_apptimer_id, APP_TIMER_TICKS(5000, 0), NULL);
}


static void services_init(void)
{
    uint32_t err_code;
    ble_lbs_init_t init;

    init.led_write_handler = led_write_handler;

    err_code = ble_lbs_init(&m_lbs, &init);
    APP_ERROR_CHECK(err_code);
}


/**@brief Function for putting the chip into sleep mode.
 *
 * @note This function will not return.
 */
static void sleep_mode_enter(void)
{
    uint32_t err_code = bsp_indication_set(BSP_INDICATE_IDLE);
    APP_ERROR_CHECK(err_code);

    // Prepare wakeup buttons.
    err_code = bsp_btn_ble_sleep_mode_prepare();
    APP_ERROR_CHECK(err_code);

    // Go to system-off mode (this function will not return; wakeup will cause a reset).
    err_code = sd_power_system_off();
    APP_ERROR_CHECK(err_code);
}


/**@brief Function for handling advertising events.
 *
 * @details This function will be called for advertising events which are passed to the application.
 *
 * @param[in] ble_adv_evt  Advertising event.
 */
static void on_adv_evt(ble_adv_evt_t ble_adv_evt)
{
    uint32_t err_code;

    switch (ble_adv_evt)
    {
    case BLE_ADV_EVT_FAST:
        err_code = bsp_indication_set(BSP_INDICATE_ADVERTISING);
        APP_ERROR_CHECK(err_code);
        break;
    case BLE_ADV_EVT_IDLE:
			  // Never sleep, always advertise.
				ble_advertising_start(BLE_ADV_MODE_FAST);
        //sleep_mode_enter();
        break;
    default:
        break;
    }
}


/**@brief Function for handling the Application's BLE Stack events.
 *
 * @param[in] p_ble_evt  Bluetooth stack event.
 */
static void on_ble_evt(ble_evt_t * p_ble_evt)
{
    uint32_t err_code;

    switch (p_ble_evt->header.evt_id)
    {
    case BLE_GAP_EVT_CONNECTED:
        err_code = bsp_indication_set(BSP_INDICATE_CONNECTED);
        APP_ERROR_CHECK(err_code);
        m_conn_handle = p_ble_evt->evt.gap_evt.conn_handle;
        break;

    case BLE_GAP_EVT_DISCONNECTED:
        m_conn_handle = BLE_CONN_HANDLE_INVALID;
        break;

    default:
        // No implementation needed.
        break;
    }
}


/**@brief Function for dispatching a BLE stack event to all modules with a BLE stack event handler.
 *
 * @details This function is called from the BLE Stack event interrupt handler after a BLE stack
 *          event has been received.
 *
 * @param[in] p_ble_evt  Bluetooth stack event.
 */
static void ble_evt_dispatch(ble_evt_t * p_ble_evt)
{
    dm_ble_evt_handler(p_ble_evt);
    ble_conn_params_on_ble_evt(p_ble_evt);
    bsp_btn_ble_on_ble_evt(p_ble_evt);
    on_ble_evt(p_ble_evt);
    ble_advertising_on_ble_evt(p_ble_evt);
    ble_lbs_on_ble_evt(&m_lbs, p_ble_evt);

}


/**@brief Function for dispatching a system event to interested modules.
 *
 * @details This function is called from the System event interrupt handler after a system
 *          event has been received.
 *
 * @param[in] sys_evt  System stack event.
 */
static void sys_evt_dispatch(uint32_t sys_evt)
{
    pstorage_sys_event_handler(sys_evt);
    ble_advertising_on_sys_evt(sys_evt);
}


/**@brief Function for initializing the BLE stack.
 *
 * @details Initializes the SoftDevice and the BLE event interrupt.
 */
static void ble_stack_init(void)
{
    uint32_t err_code;

    // Initialize the SoftDevice handler module.
    SOFTDEVICE_HANDLER_INIT( NRF_CLOCK_LFCLKSRC_RC_250_PPM_4000MS_CALIBRATION, NULL);

#if defined(S110) || defined(S130)
    // Enable BLE stack.
    ble_enable_params_t ble_enable_params;
    memset(&ble_enable_params, 0, sizeof(ble_enable_params));
#ifdef S130
    ble_enable_params.gatts_enable_params.attr_tab_size   = BLE_GATTS_ATTR_TAB_SIZE_DEFAULT;
#endif
    ble_enable_params.gatts_enable_params.service_changed = IS_SRVC_CHANGED_CHARACT_PRESENT;
    err_code = sd_ble_enable(&ble_enable_params);
    APP_ERROR_CHECK(err_code);
#endif

    // Register with the SoftDevice handler module for BLE events.
    err_code = softdevice_ble_evt_handler_set(ble_evt_dispatch);
    APP_ERROR_CHECK(err_code);

    // Register with the SoftDevice handler module for BLE events.
    err_code = softdevice_sys_evt_handler_set(sys_evt_dispatch);
    APP_ERROR_CHECK(err_code);
}


/**@brief Function for handling events from the BSP module.
 *
 * @param[in]   event   Event generated by button press.
 */
void bsp_event_handler(bsp_event_t event)
{
    uint32_t err_code;
    switch (event)
    {
    case BSP_EVENT_SLEEP:
        sleep_mode_enter();
        break;

    case BSP_EVENT_DISCONNECT:
        err_code = sd_ble_gap_disconnect(m_conn_handle, BLE_HCI_REMOTE_USER_TERMINATED_CONNECTION);
        if (err_code != NRF_ERROR_INVALID_STATE)
        {
            APP_ERROR_CHECK(err_code);
        }
        break;

    case BSP_EVENT_WHITELIST_OFF:
        err_code = ble_advertising_restart_without_whitelist();
        if (err_code != NRF_ERROR_INVALID_STATE)
        {
            APP_ERROR_CHECK(err_code);
        }
        break;

    default:
        break;
    }
}


/**@brief Function for handling the Device Manager events.
 *
 * @param[in] p_evt  Data associated to the device manager event.
 */
static uint32_t device_manager_evt_handler(dm_handle_t const * p_handle,
                                           dm_event_t const  * p_event,
                                           ret_code_t        event_result)
{
    APP_ERROR_CHECK(event_result);

#ifdef BLE_DFU_APP_SUPPORT
    if (p_event->event_id == DM_EVT_LINK_SECURED)
    {
        app_context_load(p_handle);
    }
#endif // BLE_DFU_APP_SUPPORT

    return NRF_SUCCESS;
}


/**@brief Function for the Device Manager initialization.
 *
 * @param[in] erase_bonds  Indicates whether bonding information should be cleared from
 *                         persistent storage during initialization of the Device Manager.
 */
static void device_manager_init(bool erase_bonds)
{
    uint32_t               err_code;
    dm_init_param_t        init_param = {.clear_persistent_data = erase_bonds};
    dm_application_param_t register_param;

    // Initialize persistent storage module.
    err_code = pstorage_init();
    APP_ERROR_CHECK(err_code);

    err_code = dm_init(&init_param);
    APP_ERROR_CHECK(err_code);

    memset(&register_param.sec_param, 0, sizeof(ble_gap_sec_params_t));

    register_param.sec_param.bond         = SEC_PARAM_BOND;
    register_param.sec_param.mitm         = SEC_PARAM_MITM;
    register_param.sec_param.io_caps      = SEC_PARAM_IO_CAPABILITIES;
    register_param.sec_param.oob          = SEC_PARAM_OOB;
    register_param.sec_param.min_key_size = SEC_PARAM_MIN_KEY_SIZE;
    register_param.sec_param.max_key_size = SEC_PARAM_MAX_KEY_SIZE;
    register_param.evt_handler            = device_manager_evt_handler;
    register_param.service_type           = DM_PROTOCOL_CNTXT_GATT_SRVR_ID;

    err_code = dm_register(&m_app_handle, &register_param);
    APP_ERROR_CHECK(err_code);
}


/**@brief Function for initializing the Advertising functionality.
 */
static void advertising_init(void)
{
    uint32_t      err_code;
    ble_advdata_t advdata;

    //ble_uuid_t m_adv_uuids[] = {{BLE_UUID_DEVICE_INFORMATION_SERVICE, BLE_UUID_TYPE_BLE}, {LBS_UUID_SERVICE, m_lbs.uuid_type}};
    //ble_uuid_t m_adv_uuids[] = {{BLE_UUID_DEVICE_INFORMATION_SERVICE, BLE_UUID_TYPE_BLE}};
    ble_uuid_t m_adv_uuids[] = {{BLE_UUID_DEVICE_INFORMATION_SERVICE, BLE_UUID_TYPE_BLE}, {LBS_UUID_SERVICE, BLE_UUID_TYPE_BLE}}; /**< Universally unique service identifiers. */


    // Build advertising data struct to pass into @ref ble_advertising_init.
    memset(&advdata, 0, sizeof(advdata));

    advdata.name_type               = BLE_ADVDATA_FULL_NAME;
    advdata.include_appearance      = true;
    advdata.flags                   = BLE_GAP_ADV_FLAGS_LE_ONLY_GENERAL_DISC_MODE;
    advdata.uuids_complete.uuid_cnt = sizeof(m_adv_uuids) / sizeof(m_adv_uuids[0]);
    advdata.uuids_complete.p_uuids  = m_adv_uuids;

    ble_adv_modes_config_t options = {0};
    options.ble_adv_fast_enabled  = BLE_ADV_FAST_ENABLED;
    options.ble_adv_fast_interval = APP_ADV_INTERVAL;
    options.ble_adv_fast_timeout  = APP_ADV_TIMEOUT_IN_SECONDS;

    err_code = ble_advertising_init(&advdata, NULL, &options, on_adv_evt, NULL);
    APP_ERROR_CHECK(err_code);
}


/**@brief Function for initializing buttons and leds.
 *
 * @param[out] p_erase_bonds  Will be true if the clear bonding button was pressed to wake the application up.
 */
static void buttons_leds_init(bool * p_erase_bonds)
{
    bsp_event_t startup_event;

    uint32_t err_code = bsp_init(BSP_INIT_LED | BSP_INIT_BUTTONS,
                                 APP_TIMER_TICKS(100, APP_TIMER_PRESCALER),
                                 bsp_event_handler);
    APP_ERROR_CHECK(err_code);

    err_code = bsp_btn_ble_init(NULL, &startup_event);
    APP_ERROR_CHECK(err_code);

    *p_erase_bonds = (startup_event == BSP_EVENT_CLEAR_BONDING_DATA);
}


/**@brief Function for the Power manager.
 */
static void power_manage(void)
{
    uint32_t err_code = sd_app_evt_wait();
    APP_ERROR_CHECK(err_code);
}


void app_error_handler(uint32_t error_code, uint32_t line_num, const uint8_t * p_file_name)
{
    for(;;) {
        printf( "%"PRIu32"", error_code);
        printf( "%"PRIu32"", line_num);
        printf( "%s", p_file_name);
    }
}

/**@brief Function for application main entry.
 */
int main(void)
{
    uint32_t err_code;
    bool erase_bonds;


    // Initialize.
    timers_init();

    error_init();

    buttons_leds_init(&erase_bonds);

    twi_master_init();

    pca9685_init();

    fantach_init();

    ble_stack_init();

    services_init();

    device_manager_init(erase_bonds);

    gap_params_init();

    advertising_init();

    conn_params_init();

    // Start execution.
    application_timers_start();

    err_code = ble_advertising_start(BLE_ADV_MODE_FAST);

    APP_ERROR_CHECK(err_code);

    // Enter main loop.
    for (;;)
    {
        power_manage();
    }
}

/**
 * @}
 */

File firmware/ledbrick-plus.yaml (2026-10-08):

# Configure timezone here (change this to your timezone)
substitutions:
  sntp_timezone: "America/Los_Angeles"  # Examples: "Europe/London", "America/New_York", "Asia/Tokyo"

esphome:
  name: ledbrickplus
  friendly_name: ledbrickplus
  min_version: 2026.9.0
  project:
    name: "ledbrick.plus"
    version: "__VERSION__"
  on_boot:
    - priority: 600
      then:
        - lambda: |-
            // Register all color text sensors with the scheduler
            id(main_scheduler).add_color_text_sensor(0, id(ch1_color));
            id(main_scheduler).add_color_text_sensor(1, id(ch2_color));
            id(main_scheduler).add_color_text_sensor(2, id(ch3_color));
            id(main_scheduler).add_color_text_sensor(3, id(ch4_color));
            id(main_scheduler).add_color_text_sensor(4, id(ch5_color));
            id(main_scheduler).add_color_text_sensor(5, id(ch6_color));
            id(main_scheduler).add_color_text_sensor(6, id(ch7_color));
            id(main_scheduler).add_color_text_sensor(7, id(ch8_color));
            ESP_LOGI("main", "Color text sensors registered with scheduler");
            
            // Force initial color sensor updates
            for (int i = 0; i < 8; i++) {
              std::string color = id(main_scheduler).get_channel_color(i);
              ESP_LOGI("main", "Initial color for channel %d: %s", i, color.c_str());
            }
            id(main_scheduler).update_color_sensors();
            
            // Register all light entities with the scheduler
            id(main_scheduler).add_light(0, id(lpwm1));
            id(main_scheduler).add_light(1, id(lpwm2));
            id(main_scheduler).add_light(2, id(lpwm3));
            id(main_scheduler).add_light(3, id(lpwm4));
            id(main_scheduler).add_light(4, id(lpwm5));
            id(main_scheduler).add_light(5, id(lpwm6));
            id(main_scheduler).add_light(6, id(lpwm7));
            id(main_scheduler).add_light(7, id(lpwm8));
            ESP_LOGI("main", "Light entities registered with scheduler");
            
            // Register all current controls with the scheduler
            id(main_scheduler).add_current_control(0, id(current_1));
            id(main_scheduler).add_current_control(1, id(current_2));
            id(main_scheduler).add_current_control(2, id(current_3));
            id(main_scheduler).add_current_control(3, id(current_4));
            id(main_scheduler).add_current_control(4, id(current_5));
            id(main_scheduler).add_current_control(5, id(current_6));
            id(main_scheduler).add_current_control(6, id(current_7));
            id(main_scheduler).add_current_control(7, id(current_8));
            ESP_LOGI("main", "Current controls registered with scheduler");
            
            // Register max current controls with the scheduler
            id(main_scheduler).add_max_current_control(0, id(max_current_1));
            id(main_scheduler).add_max_current_control(1, id(max_current_2));
            id(main_scheduler).add_max_current_control(2, id(max_current_3));
            id(main_scheduler).add_max_current_control(3, id(max_current_4));
            id(main_scheduler).add_max_current_control(4, id(max_current_5));
            id(main_scheduler).add_max_current_control(5, id(max_current_6));
            id(main_scheduler).add_max_current_control(6, id(max_current_7));
            id(main_scheduler).add_max_current_control(7, id(max_current_8));
            ESP_LOGI("main", "Max current controls registered with scheduler");

            // Configure temperature control
            // Fan connections
            id(main_scheduler).set_fan(id(fan_output));
            id(main_scheduler).set_fan_power_switch(id(fan_pwr));
            id(main_scheduler).set_fan_speed_sensor(id(fan_speed));


            // Configure temperature monitoring sensors
            id(main_scheduler).set_current_temp_sensor(id(temp_control_current));
            id(main_scheduler).set_target_temp_sensor(id(temp_control_target));
            id(main_scheduler).set_fan_pwm_sensor(id(temp_control_fan_pwm));
            id(main_scheduler).set_pid_error_sensor(id(temp_control_pid_error));
            id(main_scheduler).set_pid_output_sensor(id(temp_control_pid_output));
            id(main_scheduler).set_thermal_emergency_sensor(id(thermal_emergency));
            id(main_scheduler).set_fan_enabled_sensor(id(temp_control_fan_active));
            id(main_scheduler).set_enable_switch(id(temp_control_enable));
            
            ESP_LOGI("main", "Temperature control configuration complete");

dashboard_import:
  package_import_url: github://theatrus/ledbrick/firmware/ledbrick-plus.yaml@master
  import_full_config: false


esp32:
  board: esp32-s3-devkitc-1
  flash_size: 8MB
  framework:
    type: esp-idf

# Enable logging
logger:
  level: DEBUG

# Enable Home Assistant API
api:
  encryption:
    key: !secret api_encryption_key
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

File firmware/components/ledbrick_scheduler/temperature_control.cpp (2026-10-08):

#include "temperature_control.h"
#include "cJSON.h"
#include <algorithm>
#include <cmath>
#include <sstream>

#ifdef ESP_PLATFORM
#include "esp_log.h"
static const char* TAG = "TemperatureControl";
#define LOG_INFO(fmt, ...) ESP_LOGI(TAG, fmt, ##__VA_ARGS__)
#define LOG_WARN(fmt, ...) ESP_LOGW(TAG, fmt, ##__VA_ARGS__)
#define LOG_ERROR(fmt, ...) ESP_LOGE(TAG, fmt, ##__VA_ARGS__)
#else
#include <iostream>
#define LOG_INFO(fmt, ...) printf("[INFO] " fmt "\n", ##__VA_ARGS__)
#define LOG_WARN(fmt, ...) printf("[WARN] " fmt "\n", ##__VA_ARGS__)
#define LOG_ERROR(fmt, ...) printf("[ERROR] " fmt "\n", ##__VA_ARGS__)
#endif

namespace ledbrick {

// Temperature Control Implementation
TemperatureControl::TemperatureControl()
    : pid_controller_(2.0f, 0.1f, 0.5f, 0.0f, 100.0f),
      emergency_countdown_active_(false), emergency_triggered_ms_(0),
      last_update_ms_(0), last_fan_update_ms_(0),
      last_valid_temp_ms_(0), last_pid_compute_temp_ms_(0), pid_has_computed_(false),
      filtered_temperature_(0.0f), ever_had_valid_temp_(false) {

    status_.enabled = false;
    status_.target_temp_c = config_.target_temp_c;

    pid_controller_.set_target(config_.target_temp_c);
}

void TemperatureControl::set_config(const TemperatureControlConfig& config) {
    config_ = config;
    
    // Update PID controller
    pid_controller_.set_target(config_.target_temp_c);
    // For cooling: use negative gains so that when temp > target, we get positive output
    pid_controller_.set_tunings(-config_.kp, -config_.ki, -config_.kd);
    pid_controller_.set_output_limits(0.0f, config_.max_fan_pwm);
    
    status_.target_temp_c = config_.target_temp_c;
    
    LOG_INFO("Temperature control config updated - Target: %.1f°C, PID: %.2f/%.3f/%.2f",
             config_.target_temp_c, config_.kp, config_.ki, config_.kd);
}

void TemperatureControl::add_temperature_sensor(const std::string& name) {
    // Check if sensor already exists
    for (auto& sensor : sensors_) {
        if (sensor.name == name) {
            LOG_WARN("Temperature sensor '%s' already exists", name.c_str());
            return;
        }
    }
    
    TemperatureSensor sensor;
    sensor.name = name;
    sensor.temperature_c = 0.0f;
    sensor.valid = false;
    sensor.last_update_ms = 0;
    sensor.last_report_ms = 0;
    sensor.failed_readings = 0;

    sensors_.push_back(sensor);
    LOG_INFO("Added temperature sensor: %s", name.c_str());
}

void TemperatureControl::update_temperature_sensor(const std::string& name, float temp_c, uint32_t timestamp_ms) {
    for (auto& sensor : sensors_) {
        if (sensor.name == name) {
            sensor.temperature_c = temp_c;
            sensor.valid = true;
            sensor.last_update_ms = timestamp_ms;
            sensor.last_report_ms = timestamp_ms;
            sensor.failed_readings = 0;
            return;
        }
    }

    LOG_WARN("Temperature sensor '%s' not found for update", name.c_str());
}

void TemperatureControl::report_failed_reading(const std::string& name, uint32_t timestamp_ms) {
    for (auto& sensor : sensors_) {
        if (sensor.name == name) {
            sensor.last_report_ms = timestamp_ms;
            if (sensor.failed_readings <= MAX_FAILED_READINGS) {
                sensor.failed_readings++;
                if (sensor.failed_readings > MAX_FAILED_READINGS && sensor.valid) {
                    LOG_WARN("Temperature sensor '%s' failed %u readings in a row; ignoring it until it reads again",
                             name.c_str(), static_cast<unsigned>(sensor.failed_readings));
                }
            }
            return;
        }
    }

    LOG_WARN("Temperature sensor '%s' not found for update", name.c_str());
}

std::vector<TemperatureSensor> TemperatureControl::get_sensors() const {
    return sensors_;
}

void TemperatureControl::enable(bool enabled) {
    if (status_.enabled == enabled) {
        return;
    }

    status_.enabled = enabled;

    if (enabled) {
        LOG_INFO("Temperature control enabled");
        pid_controller_.reset();
        pid_has_computed_ = false;
        // Note: We don't reset ever_had_valid_temp_ or last_valid_temp_ms_
        // to maintain safety state across enable/disable cycles
    } else {
        LOG_INFO("Temperature control disabled");
        // Note: Hardware state updates will be handled by TemperatureHardwareManager
        // when it receives the disable command
    }
}

TemperatureControlCommand TemperatureControl::compute_control_command(uint32_t current_time_ms) {
    // "Disabled" turns off fan control only. Thermal shutdown keeps running, so an
    // emergency can still start, and an active one ends only on a confirmed recovery.
    TemperatureControlCommand disabled_command;
    disabled_command.fan_enabled = false;
    disabled_command.fan_pwm_percent = 0.0f;
    disabled_command.emergency_state = false;
    disabled_command.override_normal_control = true;
    disabled_command.reason = "Temperature control disabled";
    
    // Update timestamp
    last_update_ms_ = current_time_ms;
    
    // Update sensor validity and get average temperature
    float avg_temp = get_average_temperature(current_time_ms);
    
    // Apply temperature filtering
    apply_temperature_filter(avg_temp);
    status_.current_temp_c = filtered_temperature_;
    
    // First check safety conditions
    TemperatureControlCommand safety_command = evaluate_safety_conditions(
        config_, status_.current_temp_c, ever_had_valid_temp_, 
        last_valid_temp_ms_, status_.sensors_valid_count, current_time_ms);
        
    if (safety_command.override_normal_control) {
        // Losing sensors must not end an active emergency; only a confirmed
        // temperature at or below recovery_temp_c clears it
        safety_command.emergency_state = status_.hardware.thermal_emergency;
        if (!status_.enabled && !safety_command.emergency_state) {
            return disabled_command;
        }
        return safety_command;
    }
    
    // Check emergency state
    TemperatureControlCommand emergency_command = evaluate_emergency_state(current_time_ms);
    if (emergency_command.override_normal_control) {
        return emergency_command;
    }
    
    // No emergency (or it just cleared)
    if (!status_.enabled) {
        return disabled_command;
    }
    
    // Normal PID control
    return compute_fan_control(current_time_ms);
}

bool TemperatureControl::emergency_reset_allowed() const {
    // A manual reset is for a latch that cannot clear itself (no working sensor). While a
    // working sensor still reads above the recovery temperature, it must not relight the LEDs.
    return status_.sensors_valid_count == 0 || status_.max_temp_c <= config_.recovery_temp_c;
}

void TemperatureControl::update_hardware_state(const TemperatureHardwareState& hardware_state) {
    status_.hardware = hardware_state;
}
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

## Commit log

2015-02-22 Emitter REV0
    [ledbrick.GM1, ledbrick.GTL, ledbrick.GTO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]
2016-01-11 Update GCC build chain
2016-01-15 PWM docs
2016-01-20 New temperature sensing path and characteristic
2016-01-29 Fan shutdown control, temp values in C, fixes to sleep, and no more connection params
    [fan_monitor.c, main.c, pca9685.c]
2016-01-30 Capture temp and fan speed, log these sensibly
2016-03-07 Driver PDF
2019-02-27 Add r1 board
    [ledbrick.PcbDoc, ledbrick.SchDoc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]
2025-09-07 Move to ledbrick classic folder
    [ledbrick_pwm.GBL, ledbrick_pwm.GBO, ledbrick_pwm.GBS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]
2025-09-07 ledbrick plus device config
2025-09-08 Change allocation of ledc
2025-09-11 Dashboards (#7)
    * Uptime
    * New sensors
    * Fix names
    * Dashes
    [ledbrick-plus.yaml]
2025-09-11 Fix moon calculations (#8)
    [ledbrick_scheduler.cpp, ledbrick_scheduler.h, test_astronomical.cpp]
2025-09-12 Always update (#9)
    * Always update
    * 5s
    * Fix PWM
    * Less often scheduler
    * Tweaking PWM
    [channel.yaml, ledbrick-plus.yaml, ledbrick_scheduler.cpp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]
2025-11-17 Startup safety2 (#11)
    * add safety checks
    * Fix web
    * Temp improvements
    * Temp control
    * Temp temp
    [ledbrick_scheduler.cpp, ledbrick_scheduler.h, ledbrick_web_server.cpp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]
2025-11-23 Refactor temperature control: Separate controller logic from hardware state (#12)
    * Refactor temperature control to separate controller logic from hardware state
    This major refactoring addresses synchronization issues between the temperature
    controller intent and actual hardware state by implementing a clean separation
    of concerns:
    **Key Changes:**
    - Split TemperatureControl into pure controller logic that returns commands
    - Added TemperatureHardwareManager to handle actual hardware state updates
    - Created testable static safety function for exception handling
    - Updated LEDBrickScheduler to use command-based interface
    - Fixed web API to read hardware state instead of controller intent
    **A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
    [ledbrick-plus.yaml, ledbrick_scheduler.cpp, ledbrick_scheduler.h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]
2026-04-19 Add Altium hardware sources for ledbrick_plus_led and rv_ledbrick_8ch
    Imports schematics, PCB, project files, EDM footprint libraries, and
    release outputs (Gerbers, NC drill, pick and place, BOM, DRC reports).
    Altium 365 remote removed; `.gitignore` updated to track Project Outputs
    while still excluding Previews, History, Project Logs, and local metadata.
    [AMPHENOL_10155435-00011LF_CMP-243-000000-3.x_t, Bill of Materials-ledbrick_plus_led.csv, Bill of Materials-rv_ledbrick_8ch.csv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]
2026-04-19 Document hardware design files in README
    Adds a "Hardware Design Files" section under LEDBrick Plus describing the
    two Altium projects now in hardware/ (ledbrick_plus_led and
    rv_ledbrick_8ch) with links to sources and release gerbers. Also fixes
    the broken emitter-board/ link — the folder moved to
    ledbrick-classic/emitter-board/ when the classic designs were
    reorganized.
2026-04-19 Correct hardware design descriptions in README
    Previous description mixed up the two boards. Re-extracted the BOM and
    hierarchy from the Altium sources with altium_monkey and rewrote the
    section:
    - rv_ledbrick_8ch is the controller / driver board: 4-layer, ESP32-S3-MINI,
    60V->12V buck, INA228 + 0.005 ohm shunt, 8x TPS922053 channels with
    per-channel inductor / Schottky / sense shunt.
    - ledbrick_plus_led is the LED emitter / pendant board that pairs with
    the controller: single-layer MCPCB with 26x LUXEON Rubix Royal Blue,
    52x LUXEON C (multiple colors), 2x VIOSYS Z5 UV, plus on-board MCP9808
    and DS18B20 temperature sensors and two Molex Pico-Lock headers.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
2026-10-08 Build on ESPHome 2026.9.1 and fix review findings (#13)
    * Build firmware against ESPHome 2026.9.1
    Pin ESPHome 2026.9.1 in CI, the Makefile and min_version, instead of
    building with whatever release is latest.
    API changes:
    - Actions take const Ts &...x and register with synchronous=True.
    - get_unit_of_measurement() is now get_unit_of_measurement_ref().
    - cv.only_with_esp_idf is gone; use cv.only_on_esp32.
    - ESPHome leaves esp_http_server out of the IDF build unless a
    component asks for it, so the web server asks for it.
    - The web server reserves its lwIP sockets (1 listener, 1 control,
    5 clients), caps httpd at that count with LRU purge, and shuts down
    receive before close, as ESPHome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
    [channel.yaml, ledbrick-plus.yaml, ledbrick_scheduler.cpp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]
2026-10-08 Dim LEDs from their datasheet curves (#14)
    Per-channel LED curve dimming: a schedule point sets one level, and the
    firmware picks the TPS922053 current and PWM from Lumileds datasheet curves
    (LUXEON C, LUXEON Rubix), with current-first or PWM-first dimming, a floor
    current and thermal compensation. Manual mode stays the default.
    - Schedule interpolated to the second for smooth ramps
    - Curves digitized from DS144 and DS309; the generator builds the firmware
    table and tools/led_curves/led_models.json from them
    - standard_led, the median LUXEON C curve rated 1.25 A, stands in for any
    LED without a model (the violet string's UV LEDs, boards without an LED
    map, missing models)
    - As-built L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
    [read_regs.cfg]
2026-10-09 Report and scale moonlight by the share of the moon that is lit (#16)
    moon_phase is the position in the lunar cycle (0 new, 0.5 full), but the
    status bar printed it as a percentage, so a thin crescent read "Moon: 94%".
    Moonlight also scaled on a straight line between new and full, so a
    3%-lit crescent gave about 16% of the moon settings.
    - get_moon_illumination: the share lit, (1 - cos) / 2 of the cycle
    - Moonlight phase scaling uses it
    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
2026-10-09 Allow for the light each PWM pulse loses (#15)
    Measured with the LEDs powered (INA228 supply current against duty on
    RBCen and CW, 105 mA to 1.2 A): each EN/PWM pulse loses about 19 us of
    light, 1.9% of the 1 kHz period, setting in sharply at high current and
    gradually at the floor currents. The TPS922053 rounds the ADIM duty down.
    - DriveLimits models the loss; the curve dimmer raises pulsed duties to
    give the intended light and keeps them at or below 97.5%
    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
2026-10-10 Make saved settings load back, and report failed saves (#17)
    Settings that the firmware accepted could fail to load after a restart:
    - A 0.05 A floor current, the UI's minimum, was checked as a float when
    set and as the saved double on load. 0.05f is a little over 0.05, so
    the saved schedule failed to load and the device ran the default
    preset at full brightness. Compare as floats on load too.
    - Custom LED models saved max_current to 3 decimals and curve points to
    4 significant digits, so 0.6875 A saved as 0.688, past the curve's
    last point, and every custom model was dropped at boot. Read and save
    every model number with 4 significant digits, so a model is checked at
    the prec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
2026-10-10 Remove the jump near the top of curve ramps and convert manual light by the delivered step (#18)
    - Near the top of every ramp no pulsed duty fits: 97.5% gives about
    95.6% of the top step's light, and 100% gives all of it. The dimmer
    took whichever was nearer, so levels 95.6% to 97.9% all gave 95.6%
    and the next second jumped 4.6%, on all 8 channels in both modes. It
    now runs the step whose full output is nearest the level, at 100%;
    the largest step between neighbouring levels is 0.66%. In PWM-first
    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
